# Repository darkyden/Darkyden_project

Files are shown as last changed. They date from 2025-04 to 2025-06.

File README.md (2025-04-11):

# 💻 Diagrammes de cas d'utilisation – Laptop CM3588 Plus

## 🎯 1. Cas d'utilisation – Point de vue de l’utilisateur

```
[État initial : OFF]
    |
    | Appui bouton power (debounce 50 ms)
    v
[BOOTLOADER]
    |
    | Chargement du bootloader (delay: 1-3 sec)
    v
[OS Linux chargé]
    |
    | - Interface graphique active
    | - Réseau détecté?
    |       |-- Oui --> Connexion automatique (delay: 3-5 sec)
    |       |-- Non --> Affichage de l'outil de sélection réseau
    v
[Écran d’accueil / Bureau]
    |
    | Actions possibles :
    | - Lancer terminal
    | - Ouvrir navigateur
    | - Lancer analyse réseau (Nmap, Tshark)
    | - Gérer fichiers
    | - Mise en veille automatique après 10 min inactivité
    |
    | Mise en veille : Appui touche ou pad → Retour bureau (delay: <1 sec)
    |
    | Appui long power (2 sec) → Demande de confirmation d’arrêt
    | → Oui → Arrêt propre du système (3-6 sec)
```

---

## 🧰 2. Cas d'utilisation – Point de vue du technicien

```
[État initial : OFF ou ON]
    |
    | Connexion série UART ou SSH (si actif)
    v
[Console ou TTY active]
    |
    | Tâches possibles :
    | - Flash du bootloader
    | - Modification du fstab, réseau, kernel, uboot
    | - Lecture des logs : dmesg, journalctl
    | - Diagnostic I²C / SPI / USB / PCIe
    | - Interaction GPIO (avec debounce logiciel : 10-100 ms)
    |
    | Commandes système :
    | - reboot → redémarrage (delay: ~5 sec)
    | - halt → arrêt immédiat
    |
    | Monitoring ressources :
    | - top, htop, iotop, powertop
    |
    | Maintenance :
    | - Mise à jour via apt, emerge ou pacman selon distro
    | - Scripts de test de modules (ping module Wi-Fi, test audio I2S)
```

---

## 🔁 Transitions entre états (simplifiées)

```
OFF --> [Appui bouton power] --> BOOTLOADER --> [OS Linux]
OS Linux --> [Inactivité 10 min] --> VEILLE
VEILLE --> [Mouvement souris/clavier] --> OS Linux
OS Linux --> [Appui long 2s + validation] --> SHUTDOWN
```

---

## ⏱ Détails sur les délais

| Action | Délai approximatif |
|---|---|
| Debounce bouton | 50 ms |
| Bootloader | 1 – 3 sec |
| Démarrage complet Linux | 5 – 10 sec |
| Connexion Wi-Fi | 3 – 5 sec |
| Mise en veille automatique | 10 min (paramétrable)  |
| Réveil de veille | < 1 sec |
| Arrêt complet | 3 – 6 sec |
| Temps de réponse CLI (console)  | instantané (<100 ms) |

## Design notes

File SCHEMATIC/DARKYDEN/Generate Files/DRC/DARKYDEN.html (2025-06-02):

Altium

# Design Rule Verification Report

Date: | | 2025-05-15
Time: | | 12:12:37 PM
Elapsed Time: | | 00:00:02
Filename: | | D:\gitdoc\Darkyden_project\SCHEMATIC\DARKYDEN\PCB1.PcbDoc

Warnings: | | 0
Rule Violations: | | 54

## Summary

Warnings | Count
Total | 0

Rule Violations | Count
Clearance Constraint (Gap=0.102mm) (All),(All) | 0
Clearance Constraint (Gap=0.203mm) (inpoly),(All) | 0
Short-Circuit Constraint (Allowed=No) (All),(All) | 0
Un-Routed Net Constraint ( (All) ) | 0
Modified Polygon (Allow modified: No), (Allow shelved: No) | 0
Width Constraint (Min=0.15mm) (Max=5mm) (Preferred=0.2mm) (InNet('+12')) | 0
Width Constraint (Min=0.15mm) (Max=5mm) (Preferred=0.2mm) (InNet('+3V3_NVME')) | 0
Width Constraint (Min=0.15mm) (Max=5mm) (Preferred=0.2mm) (InNet('+3V3')) | 0
Width Constraint (Min=0.15mm) (Max=5mm) (Preferred=0.2mm) (InNet('+5V')) | 0
Width Constraint (Min=0.15mm) (Max=1.27mm) (Preferred=0.152mm) (All) | 0
Width Constraint (Min=0.15mm) (Max=5mm) (Preferred=0.2mm) (InNet('+3V3_WIFI')) | 0
Width Constraint (Min=0.15mm) (Max=5mm) (Preferred=0.2mm) (InNet('+3V3_SD_SO')) | 0
Width Constraint (Min=0.2mm) (Max=0.406mm) (Preferred=0.381mm) (InNet('GND')) | 0
Width Constraint (Min=0.15mm) (Max=5mm) (Preferred=0.2mm) (InNet('+3V3_SD_SO')) | 0
Width Constraint (Min=0.15mm) (Max=5mm) (Preferred=0.2mm) (InNet('+3V3_PI6C')) | 0
Width Constraint (Min=0.15mm) (Max=5mm) (Preferred=0.2mm) (InNet('+1V8')) | 0
Power Plane Connect Rule(Relief Connect )(Expansion=0.508mm) (Conductor Width=0.254mm) (Air Gap=0.254mm) (Entries=4) (All) | 0
Matched Lengths(Tolerance=0.152mm) (InDifferentialPairClass('NVME_DIFF')) | 8
Matched Lengths(Tolerance=50mm) (InDifferentialPairClass('NVME_DIFF')) | 21
Matched Lengths(Tolerance=50mm) (InDifferentialPairClass('WIFI_DIFF')) | 4
Matched Lengths(Tolerance=0.152mm) (InDifferentialPairClass('WIFI_DIFF')) | 4
Matched Lengths(Tolerance=50mm) (InDifferentialPairClass('eDP')) | 0
Matched Lengths(Tolerance=0.152mm) (InDifferentialPairClass('Ethernet')) | 4
Matched Lengths(Tolerance=50mm) (InDifferentialPairClass('Ethernet')) | 0
Matched Lengths(Tolerance=0.152mm) (InDifferentialPairClass('eDP')) | 0
Matched Lengths(Tolerance=50mm) (InDifferentialPairClass('USBC_A') or InDifferentialPairClass('USBC_B')) | 9
Matched Lengths(Tolerance=0.152mm) (InDifferentialPairClass('USBC_A') or InDifferentialPairClass('USBC_B')) | 4
Total | 54

Matched Lengths(Tolerance=0.152mm) (InDifferentialPairClass('NVME_DIFF'))

Matched Net Lengths: Between Net NVME_REFCLK_A_N And Net NVME_REFCLK_A_P Actual Difference against NVME_REFCLK_A_P is: 1.472mm, Tolerance : 0.152mm.

Matched Net Lengths: Between Net PCIE30_PORT0_IN_REFCLK_N And Net PCIE30_PORT0_IN_REFCLK_P Actual Difference against PCIE30_PORT0_IN_REFCLK_P is: 0.223mm, Tolerance : 0.152mm.

Matched Net Lengths: Between Net PCIE30_PORT0_RX1_N And Net PCIE30_PORT0_RX1_P Actual Difference against PCIE30_PORT0_RX1_P is: 0.46mm, Tolerance : 0.152mm.

Matched Net Lengths: Between Net PCIE30_PORT1_IN_REFCLK_N And Net PCIE30_PORT1_IN_REFCLK_P Actual Difference against PCIE30_PORT1_IN_REFCLK_P is: 1.674mm, Tolerance : 0.152mm.

Matched Net Lengths: Between Net PCIE30_PORT1_RX2_N And Net PCIE30_PORT1_RX2_P Actual Difference against PCIE30_PORT1_RX2_P is: 0.206mm, Tolerance : 0.152mm.

Matched Net Lengths: Between Net PCIE30_PORT1_RX3_N And Net PCIE30_PORT1_RX3_P Actual Difference against PCIE30_PORT1_RX3_P is: 3.197mm, Tolerance : 0.152mm.

Matched Net Lengths: Between Net PCIE30_PORT1_TX2_N And Net PCIE30_PORT1_TX2_P Actual Difference against PCIE30_PORT1_TX2_P is: 0.196mm, Tolerance : 0.152mm.

Matched Net Lengths: Between Net WIFI_REFCLK_A_N And Net WIFI_REFCLK_A_P Actual Difference against WIFI_REFCLK_A_P is: 0.48mm, Tolerance : 0.152mm.

Back to top

Matched Lengths(Tolerance=50mm) (InDifferentialPairClass('NVME_DIFF'))

Matched Net Lengths: Differential Pair CLK Actual Length Difference against diff pair PCIE30_PORT1_RX3 is: 96.648mm, Length Tolerance : 50mm.

Matched Net Lengths: Differential Pair CLK1 Actual Length Difference against diff pair PCIE30_PORT1_RX3 is: 98.442mm, Length Tolerance : 50mm.

Matched Net Lengths: Differential Pair CLK2 Actual Length Difference against diff pair PCIE30_PORT1_RX3 is: 98.594mm, Length Tolerance : 50mm.

Matched Net Lengths: Differential Pair CLK3 Actual Length Difference against diff pair PCIE30_PORT1_RX3 is: 96.796mm, Length Tolerance : 50mm.

Matched Net Lengths: Differential Pair PCIE30_PORT0_IN_REFCLK Actual Length Difference against diff pair PCIE30_PORT1_RX3 is: 87.589mm, Length Tolerance : 50mm.

Matched Net Lengths: Differential Pair PCIE30_PORT1_IN_REFCLK Actual Length Difference against diff pair PCIE30_PORT1_RX3 is: 79.867mm, Length Tolerance : 50mm.

Matched Net Lengths: Differential Pair WIFI_REFCLK_A Actual Length Difference against diff pair PCIE30_PORT1_RX3 is: 67.314mm, Length Tolerance : 50mm.

Matched Net Lengths: Between Net CLK_N And Net PCIE30_PORT1_RX3_P Length:7.098mm is not within 50mm tolerance of Length:105.345mm (48.246mm short)

Matched Net Lengths: Between Net CLK_P And Net PCIE30_PORT1_RX3_P Length:7.098mm is not within 50mm tolerance of Length:105.345mm (48.246mm short)

Matched Net Lengths: Between Net CLK1_N And Net PCIE30_PORT1_RX3_P Length:5.305mm is not within 50mm tolerance of Length:105.345mm (50.04mm short)

Matched Net Lengths: Between Net CLK1_P And Net PCIE30_PORT1_RX3_P Length:5.305mm is not within 50mm tolerance of Length:105.345mm (50.04mm short)

Matched Net Lengths: Between Net CLK2_N And Net PCIE30_PORT1_RX3_P Length:5.152mm is not within 50mm tolerance of Length:105.345mm (50.192mm short)

Matched Net Lengths: Between Net CLK2_P And Net PCIE30_PORT1_RX3_P Length:5.152mm is not within 50mm tolerance of Length:105.345mm (50.192mm short)

Matched Net Lengths: Between Net CLK3_N And Net PCIE30_PORT1_RX3_P Length:6.95mm is not within 50mm tolerance of Length:105.345mm (48.394mm short)

Matched Net Lengths: Between Net CLK3_P And Net PCIE30_PORT1_RX3_P Length:6.95mm is not within 50mm tolerance of Length:105.345mm (48.394mm short)

Matched Net Lengths: Between Net PCIE30_PORT0_IN_REFCLK_N And Net PCIE30_PORT1_RX3_P Length:16.045mm is not within 50mm tolerance of Length:105.345mm (39.299mm short)

Matched Net Lengths: Between Net PCIE30_PORT0_IN_REFCLK_P And Net PCIE30_PORT1_RX3_P Length:16.268mm is not within 50mm tolerance of Length:105.345mm (39.076mm short)

Matched Net Lengths: Between Net PCIE30_PORT1_IN_REFCLK_N And Net PCIE30_PORT1_RX3_P Length:23.043mm is not within 50mm tolerance of Length:105.345mm (32.302mm short)

Matched Net Lengths: Between Net PCIE30_PORT1_IN_REFCLK_P And Net PCIE30_PORT1_RX3_P Length:24.717mm is not within 50mm tolerance of Length:105.345mm (30.628mm short)

Matched Net Lengths: Between Net PCIE30_PORT1_RX3_P And Net WIFI_REFCLK_A_N Length:36.192mm is not within 50mm tolerance of Length:105.345mm (19.152mm short)

Matched Net Lengths: Between Net PCIE30_PORT1_RX3_P And Net WIFI_REFCLK_A_P Length:36.672mm is not within 50mm tolerance of Length:105.345mm (18.672mm short)

Back to top

Matched Lengths(Tolerance=50mm) (InDifferentialPairClass('WIFI_DIFF'))

Matched Net Lengths: Differential Pair WIFI_REFCLK_A Actual Length Difference against diff pair USB20_HOST1_D is: 77.598mm, Length Tolerance : 50mm.

Matched Net Lengths: Between Net PCIE20_1_TX_N And Net USB20_HOST1_D_P Length:63.948mm is not within 50mm tolerance of Length:114.272mm (0.324mm short)

Matched Net Lengths: Between Net USB20_HOST1_D_P And Net WIFI_REFCLK_A_N Length:36.192mm is not within 50mm tolerance of Length:114.272mm (28.08mm short)

Matched Net Lengths: Between Net USB20_HOST1_D_P And Net WIFI_REFCLK_A_P Length:36.672mm is not within 50mm tolerance of Length:114.272mm (27.6mm short)

Back to top

Matched Lengths(Tolerance=0.152mm) (InDifferentialPairClass('WIFI_DIFF'))

Matched Net Lengths: Between Net PCIE20_1_RX_N And Net PCIE20_1_RX_P Actual Difference against PCIE20_1_RX_P is: 1.02mm, Tolerance : 0.152mm.

Matched Net Lengths: Between Net PCIE20_1_TX_N And Net PCIE20_1_TX_P Actual Difference against PCIE20_1_TX_P is: 0.454mm, Tolerance : 0.152mm.

Matched Net Lengths: Between Net USB20_HOST1_D_N And Net USB20_HOST1_D_P Actual Difference against USB20_HOST1_D_P is: 0.484mm, Tolerance : 0.152mm.

Matched Net Lengths: Between Net WIFI_REFCLK_A_N And Net WIFI_REFCLK_A_P Actual Difference against WIFI_REFCLK_A_P is: 0.48mm, Tolerance : 0.152mm.

Back to top

Matched Lengths(Tolerance=0.152mm) (InDifferentialPairClass('Ethernet'))

Matched Net Lengths: Between Net P25G_MDI0_N And Net P25G_MDI0_P Actual Difference against P25G_MDI0_P is: 1.032mm, Tolerance : 0.152mm.

Matched Net Lengths: Between Net P25G_MDI1_N And Net P25G_MDI1_P Actual Difference against P25G_MDI1_P is: 2.328mm, Tolerance : 0.152mm.

Matched Net Lengths: Between Net P25G_MDI2_N And Net P25G_MDI2_P Actual Difference against P25G_MDI2_P is: 1.228mm, Tolerance : 0.152mm.

Matched Net Lengths: Between Net P25G_MDI3_N And Net P25G_MDI3_P Actual Difference against P25G_MDI3_P is: 1.979mm, Tolerance : 0.152mm.

Back to top

Matched Lengths(Tolerance=50mm) (InDifferentialPairClass('USBC_A') or InDifferentialPairClass('USBC_B'))

Matched Net Lengths: Differential Pair TYPEC0_D Actual Length Difference against diff pair TYPEC1_OTG_D is: 91.41mm, Length Tolerance : 50mm.

Matched Net Lengths: Differential Pair TYPEC0_OTG Actual Length Difference against diff pair TYPEC1_OTG_D is: 54.508mm, Length Tolerance : 50mm.

Matched Net Lengths: Differential Pair TYPEC1_D Actual Length Difference against diff pair TYPEC1_OTG_D is: 90.068mm, Length Tolerance : 50mm.

Matched Net Lengths: Between Net TYPEC0_D_N And Net TYPEC1_OTG_D_P Length:21.341mm is not within 50mm tolerance of Length:113.87mm (42.529mm short)

Matched Net Lengths: Between Net TYPEC0_D_P And Net TYPEC1_OTG_D_P Length:21.418mm is not within 50mm tolerance of Length:113.87mm (42.453mm short)

Matched Net Lengths: Between Net TYPEC0_OTG_N And Net TYPEC1_OTG_D_P Length:58.587mm is not within 50mm tolerance of Length:113.87mm (5.283mm short)

Matched Net Lengths: Between Net TYPEC0_OTG_P And Net TYPEC1_OTG_D_P Length:57.976mm is not within 50mm tolerance of Length:113.87mm (5.894mm short)

Matched Net Lengths: Between Net TYPEC1_D_N And Net TYPEC1_OTG_D_P Length:22.741mm is not within 50mm tolerance of Length:113.87mm (41.13mm short)

Matched Net Lengths: Between Net TYPEC1_D_P And Net TYPEC1_OTG_D_P Length:22.703mm is not within 50mm tolerance of Length:113.87mm (41.168mm short)

Back to top

Matched Lengths(Tolerance=0.152mm) (InDifferentialPairClass('USBC_A') or InDifferentialPairClass('USBC_B'))

Matched Net Lengths: Between Net TYPEC0_OTG_N And Net TYPEC0_OTG_P Actual Difference against TYPEC0_OTG_P is: 0.611mm, Tolerance : 0.152mm.

Matched Net Lengths: Between Net TYPEC0_SSTX1_N And Net TYPEC0_SSTX1_P Actual Difference against TYPEC0_SSTX1_P is: 0.184mm, Tolerance : 0.152mm.

Matched Net Lengths: Between Net TYPEC1_OTG_D_N And Net TYPEC1_OTG_D_P Actual Difference against TYPEC1_OTG_D_P is: 2.162mm, Tolerance : 0.152mm.

Matched Net Lengths: Between Net TYPEC1_SSRX2_N And Net TYPEC1_SSRX2_P Actual Difference against TYPEC1_SSRX2_P is: 0.154mm, Tolerance : 0.152mm.

Back to top

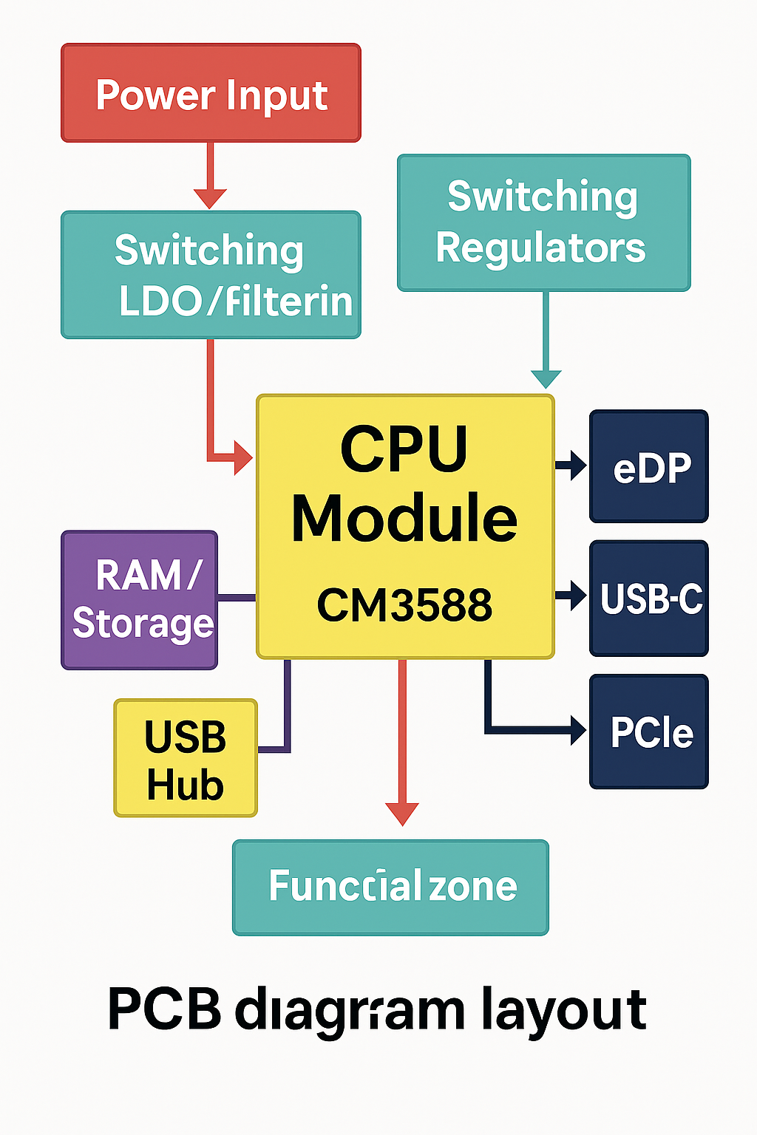
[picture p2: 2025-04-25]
DATASHEET/layout.png

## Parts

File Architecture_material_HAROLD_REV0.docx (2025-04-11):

# Projet de fin de DEC – Architecture matérielle

Projet : Laptop basé sur le CM3588 Plus
OS principal : Linux

# Architecture Matérielle

## 1. Composantes matérielles principales

- SoC principal : CM3588 Plus (CPU ARM Cortex-A76/A55, GPU Mali-G610)
- Mémoire vive (RAM) : 64bits 16Go LPDDR5 @2400MHz
- Stockage principal : SSD NVMe via M.2
- Wi-Fi / Bluetooth : Module Intel AX210 (Wi-Fi 6E, Bluetooth 5.3)
- Réseautique : Port Ethernet RJ45 Gigabit
- USB : 2 ports USB-C (dont un pour la charge), 2 ports USB 3.0 Type-A
- Affichage : Écran LCD entre 13.3 à 16 pouces via eDP
- Alimentation : Batterie Li-ion 4S (~14.8V nominal, 16.8V max), recharge via USB-C PD

## 2. Alimentation

- Type : Batterie Li-ion 4S
- Tension : 14.8V nominale, 16.8V pleine charge
- Recharge : USB-C Power Delivery via module BQ25792
- Régulation : Buck converter TPS564201 pour 3.3V, avec filtrage pour SSD, Wi-Fi

## 3. Emplacement des composantes

Disposition prévue sur le PCB : CM3588 centré, SSD à l’arrière, ports USB/C de chaque côté, batterie dessous.

## 4. Dimensions

- PCB : ~220mm x 140mm (1ere estimation)
- Composantes critiques : NVMe, AX210 (hauteur)
- Fixation : stand-offs métalliques M2.5, boîtier imprimé 3D

## 5. Analyse des pièces

- CM3588 Plus : ~80-120$
- AX210 : ~30$
- NVMe : courant
- Régulateurs TPS564201 : disponibles
- Contrôleur PD : BQ25792 (~10$)

## 6. Calculs de courant et puissance

- Total : ~15-20W
- Batterie 4S 4000mAh ≈ 60Wh ⇒ 3-4h autonomie

## 7. Analyse PCB vs impédance

PCB 6 couches, impédance contrôlée sur lignes USB 3.0, PCIe, eDP.

## 8. Schéma bloc simplifié

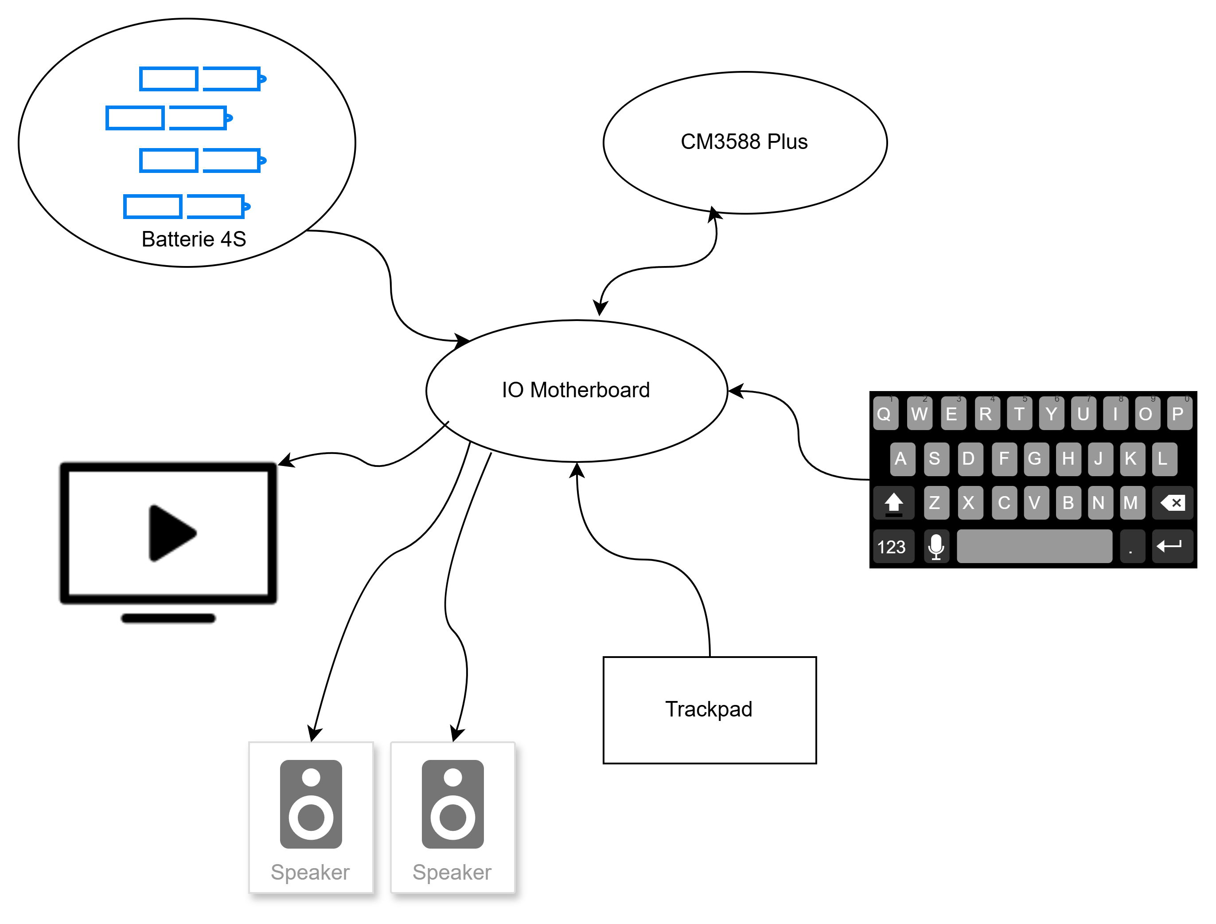
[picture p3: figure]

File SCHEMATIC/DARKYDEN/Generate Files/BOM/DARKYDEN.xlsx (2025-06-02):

LibRef | Comment | Manufacturer | Quantity | Description | Designator | Manufacturer Part Number
C0805C223J3GACTU | 22nf/25V | KEMET | 1 | 22nF, 25 V, 0805 [2012 Metric], 5%, C0G / NP0 | 66 | C0805C223J3GACTU
BGX50AE6327HTSA1 | BGX50AE6327HTSA1 | Infineon | 5 | BGX50A Series 50 V 140 mA Surface Mount Silicon Switching Diode - SOT-143 | BR1, BR2, BR3, BR4, BR5 | BGX50AE6327HTSA1
Header 1.25MM | 0530480210 |  | 4 | Connector | BT1, BT2, BT3, BT4 | 0530480210
C0805C104K9RACTU | 0.1uF/6.3V | KEMET | 19 | 0.1uF 6.3V X7R 10% Pad SMD 0805 125C T/R | C1, C156, C158, C159, C160, C162, C163, C164, C165, C166, C168, C171, C172, C175, C176, C179, C180, C183, C185 | C0805C104K5RACTU
C0805C106K9RACTU | 10uF/6.3V | KEMET | 9 | 10uF/6.3V SMD Comm X7R 0805 (2012Metric) Ceramic Capacitor 0.079Lx0.049W 2.00mmx1.25mm X7R ±10% 10muF | C2, C3, C6, C7, C12, C13, C14, C15, C35 | C0805C106K3PACTU
C0805C221M5RACTU | 220pF/50V | KEMET | 4 | Cap Ceramic 220pF 50V X7R 20% Pad SMD 0805 125C T/R | C4, C5, C19, C20 | C0805C221M5RACTU
C0805C105K9RACTU | 1uF/6.3V | KEMET | 8 | 1 uF, 6.3 V, ± 10%, X7R, 0805 [2012 Metric] Multilayer Ceramic Capacitor, | C8, C9, C10, C16, C17, C18, C21, C22 | C0805C105K3RACTU
EEE-FPJ101UAR | 100uF / 6.3V | Panasonic | 6 | 100uF 6.3V 20% Cap Aluminum Lytic SMD 0.36 Ohm 240mA 2000h 105C Automotive T/R | C11, C169, C173, C177, C181, C186 | EEE-FPJ101UAR
C0805C104K4RACAUTO | 0.1uF/16V | KEMET | 8 | 0.1uF/16V ±10% X7R 0805 (2012METRIC) Ceramic Capacitor SMD Auto X7R | C23, C24, C29, C31, C36, C45, C137, C138 | C0805C104K5RACTU
C0805C105K8RACTU | 1uF/10V | KEMET | 8 | Multilayer Ceramic Capacitors MLCC - SMD/SMT 10V 1uF X7R 0805 10% | C26, C28, C30, C32, C49, C58, C70, C79 | C0805C105K3RACTU
C0805C220J5RACTU | 22pF/50V | KEMET | 6 | Cap Ceramic 22pF 50V X7R 5% Pad SMD 0805 125°C T/R | C27, C51, C60, C72, C81, C151 | C0805C220J5RACTU
C0805C150K5RACAUTO | 15pF/50V | KEMET | 2 | Multilayer Ceramic Capacitors MLCC - SMD/SMT 50V 15pF X7R 0805 10% AEC-Q200 | C33, C34 | C0805C150K5RACAUTO
C0805C102K5RACTU | 1nF/50V | KEMET | 10 | Multilayer Ceramic Capacitor 1000 Pf 50 V ½ 10% X7R 0805 [2012 Metric] | C41, C42, C43, C44, C115, C155, C170, C174, C178, C182 | C0805C102K5RACTU
C0805C105K4RACTU | 1uF/16V | KEMET | 2 | 1uF/16 V, X7R, Surface Mount, 0805 | C46, C154 | C0805C105K3RACTU
C0805C106K3PACTU | 10uF/25V | KEMET | 43 | 10uF / 25 VDC, +85degC, X5R Dielec, +/-10% | KEMET C0805C106K3PACTU 0805 | C47, C48, C52, C53, C54, C55, C56, C57, C61, C62, C63, C64, C65, C68, C69, C73, C74, C75, C76, C77, C78, C82, C83, C84, C85, C87, C88, C89, C95, C96, C98, C99, C100, C101, C107, C108, C109, C110, C111, C113, C114, C152, C153 | C0805C106K3PACTU
C0805C104K3RACTU | 0.1uF/25V | KEMET | 11 | 0.1uF 25V X7R 10% SMD 0805 125C Plastic T/R | C50, C59, C71, C80, C94, C122, C123, C124, C126, C127, C142 | C0805C104K5RACTU
C0805C105K3RACTU | 1uF/25V | KEMET | 9 | 1 µF, 25 V (DC), ±10 %, SMD 0805, X7R, C0805C105K3RAC7800 | C67, C116, C117, C120, C121, C125, C128, C129, C131 | C0805C105K3RACTU
C0805C103K3RACTU | 10nF/25V | KEMET | 2 | 0.01uF 25V X7R 10% SMD 0805 125C Paper T/R | C86, C149 | C0805C103K3RACTU
C0805C331K3GACTU | 330pF/25V | KEMET | 2 | 330pF 25VC0G 0805 10% | C90, C91 | C0805C331K3GACTU
CL21A226MAYNNNE | 22pF/25V | Samsung | 2 | 22uF/25V 20% X5R 0805 | C92, C93 | CL21A226MAYNNNE
C0805C104K5RACTU | 0.1uF/50V | KEMET | 4 | 0.1uF/50V X7R 10% 0805 Multilayer Ceramic Capacitors Mlcc Smd/Smt Rohs | C97, C102, C106, C112 | C0805C104K5RACTU
C0805C475K4RACTU | 4.7uF/16V | KEMET | 2 | 4.7 uF, 16 V, ± 10%, X7R, 0805 [2012 Metric] | C103, C141 | C0805C475K4RACTU
C0805C473K3GACTU | 47nF/25V | KEMET | 2 | 47nF/25V C0G 10% Pad SMD 0805 125C Extreme Low ESR T/R | C104, C105 | C0805C473K3GACTU
GRM32ER61E226KE15L | 22uF/25V | Murata | 1 | 1210 22 uF 25 V ±10% Tolerance X5R SMT Multilayer Ceramic Capacitor | C132 | GRM32ER61E226KE15L
20SVPF56MX | 56uF/20V | Panasonic | 1 | 56uF 20VDC 20%( Cap Aluminum Polymer SMD 0.03 Ohm 2800mA 5000h 105C T/R 20SVPF56MX | C133 | 20SVPF56MX
35SVPF120M | 120uF/35V | Panasonic | 1 | 120uF 35VDC 20% Cap Aluminum Polymer SMD 0.018 Ohm 4400mA 5000h 105C T/R | C134 | 35SVPF120M
C3225X7R1H106M250AC | 10uF/50V | TDK | 1 | 10 uF 50 V 1210 ±20 % Tolerance X7R SMT Multilayer Ceramic Capacitor | C135 | C3225X7R1H106M250AC
C1608X5R1H105K080AB | 1uF/50V | TDK | 1 | 1uF / 50 V, X5R, Surface Mount, 0603 | C136 | C1608X5R1H105K080AB
C0805C472K4RACTU | 4.7nF/16V | KEMET | 1 | 4.7nF, 16VDC, 10-% Tol, 10+% Tol, X7R-TC Code, -15, 15%-TC RoHS Compliant: Yes | C139 | C0805C472K4RACTU
C0805C150K4GACTU | 15pF/16V | KEMET | 1 | 15 pF, 16 V, ± 10%, C0G (NP0), 0805 [2012 Metric] | C140 | C0805C150K5RACAUTO
CGA4J3X5R1H475K125AB | 4.7uF/50V | TDK | 2 | 4.7uF/50V X5R 卤10% 0805 Multilayer Ceramic Capacitors MLCC - SMD/SMT ROHS | C143, C144 | CGA4J3X5R1H475K125AB
C0805C103K5RACTU | 10nF/50V | KEMET | 1 | 10nF/50V X7R 0805 10% | C145 | C0805C103K5RACTU
T520B107M006ATE015 | 100uF/6.3V | KEMET | 1 | 100uF / 6.3VDC B CASE 20% Cap Tant Polymer SMD 3528-21 0.015 Ohm 105C T/R | C146 | T520B107M006ATE015
GRM32ER61A476KE20L | 47uF/10V | Murata | 2 | Multilayer Ceramic Capacitor, 47 uF, 10 V, ï¿½ 10%, X5R, 1210 [3225 Metric] | C147, C148 | GRM32ER61A476KE20L
C0805C222K3GECTU | 2.2nF/25V | KEMET | 1 | 2.2nF ±10% 25V Ceramic Capacitor C0G, NP0 0805 (2012 Metric) | C150 | C0805C222K3GECTU
C0805C475K9RACTU | 4.7uF / 6.3V | KEMET | 1 | 4.7uF 6.3V X7R 10% Pad SMD 0805 125C T/R | C157 | C0805C475K9RACTU
C0805C180K5RACTU | 18pF/50V | KEMET | 2 | 18PF, 50V, Mlcc, 0805; | C161, C167 | C0805C180K5RACTU
DF40HC(3.0)-100DS-0.4V(51) | DF40HC | Hirose | 4 | Stacking Board Connector, DF40 Series, Receptacle, 0.4 mm, 100, Surface Mount, G | CON1, CON2, CON3, CON4 | DF40HC(3.0)-100DS-0.4V(51
RB521S30T1G | 30V/200mA | ON Semiconductor | 1 | SCHOTTKY BARRIER DIODE Rectifier Diode, Schottky, 1 Phase, 1 Element, 0.2A, 30V V(RRM), Silicon | D3 | RB521S30T1G
BAS316_RRG | BAS316_RRG | Taiwan Semiconductor | 1 | Rectifier Diode Small Signal Switching 0.25A 4ns 2-Pin SOD-323 T/R | D4 | BAS316 RRG
SMBJ26A-13-F | SMBJ26A-13-F |  | 1 | TVS DIODE 26VWM 42.1VC SMB | D5 | SMBJ26A-13-F
MMSZ5248B-7-F | MMSZ5248B-7-F |  | 1 | Zener Diode 18 V 500 mW ±5% Surface Mount SOD-123 | D6 | MMSZ5248B-7-F
CDBC540-G | CDBC540-G | Comchip | 1 | Schottky Diode 40V 5A 2-Pin DO-214AB (SMC) CDBC540-G SMT | D7 | CDBC540-G
20455-040E-76 | 20455-040E-76 | I-PEX | 1 | Conn Wire to Board RCP 40 POS 0.5mm Solder RA Side Entry SMDCABLINE® T/R | eDP1 | 20455-040E-76
L829-1J1T-JM | L829-1J1T-JM | Bel | 1 | Modular Connectors / Ethernet Connectors 1x1 2.5GBT MagJack | ETH1 | L829-1J1T-JM
BLM18EG221SN1D | 220R / 100MHz | Murata | 11 | Ferrite Beads Multi-Layer 220Ohm 25% 100MHz 2A 50mOhm DCR 0603 Paper T/R | FB1, FB2, FB3, FB4, FB5, FB6, FB7, FB8, FB9, FB10, FB11 | BLM18EG221SN1D
AT25SF081B-SHB-T | AT25SF081B-SHB-T | Renesas | 1 | FLASH - NOR Memory IC 8Mb (1M x 8) SPI - Quad I/O 108 MHz 8-SOIC | IC4 | AT25SF081B-SHB-T
TPS564201DDCR | TPS564201DDCR | Texas Instruments | 4 | IC REG BUCK ADJ 4A SOT23 "Buck Switching Regulator IC Positive Adjustable 0.76V 1 Output 4A SOT-23-6 Thin, TSOT-23-6" | IC5, IC6, IC8, IC9 | TPS564201DDCR
RT9193-18GB | RT9193-18GB |  | 1 | Linear Voltage Regulator IC Positive Fixed 1.8V Output 300mA SOT-23-5 | IC7 | RT9193-18GB
BQ7791501PWR | BQ7791501PWR | Texas Instruments | 1 | /Polymer 3~5 TSSOP-24 Battery Management ICs ROHS | IC12 | BQ7791501PWR
TPS552882RPMR | TPS552882RPMR | Texas Instruments | 1 | 36-V, 16-A buck-boost converter 26-VQFN-HR -40 to 125 | IC14 | TPS552882RPMR
TPS54531DDA | TPS54531DDA |  | 1 | Buck Switching Regulator IC Positive Adjustable 0.8V 1 Output 5A 8-PowerSOIC (0.154", 3.90mm Width) | IC15 | TPS54531DDA
TLV75533PDBVR | TLV75533PDBVR | Texas Instruments | 1 | 500mA high-PSRR low-IQ low-dropout voltage regulator with enable 5-SOT-23 -40 to 125 | IC16 | TLV75533PDBVR
USB2514B-AEZG | USB2514B-AEZG |  | 1 | USB Hub Controller USB 2.0 USB Interface 36-QFN (6x6) | IC17 | USB2514B-AEZG
MIC2505-1YM | MIC2505-1YM |  | 1 | Power Switch/Driver 1:1 N-Channel 2A 8-SOIC | IC18 | MIC2505-1YM
MIC2026-1YM | MIC2026-1YM |  | 2 | Power Switch/Driver 1:2 N-Channel 1.25A 8-SOIC | IC19, IC20 | MIC2026-1YM
USBC | USBC |  | 3 | USB-C (USB TYPE-C) USB 3.2 Gen 2 (USB 3.1 Gen 2, Superspeed + (USB 3.1)) Receptacle Connector 24 Position Surface Mount, Right Angle; Through Hole | J2, J3, J8 | 2012670005
2328702-8 | 2328702-8 |  | 1 | Connector | J4 | 2328702-8
MSD-4-A | MicroSD |  | 1 | Micro SD Card Connector, 9 Positions, Connector and Ejector, Push In, Auto Eject Out, Surface Mount, 1.8 mm Height Above Board, Gold Flash | J7 | MSD-4-A
61300311121 | 61300311121 | Wurth Elektronik | 1 | WR-PHD Pin Header, THT, Vertical, pitch 2.54mm, 1 Row, 3P | J12 | 61300311121
61300211121 | PowerOn_btn | Wurth Electronics | 1 | THT Vertical Pin Header WR-PHD, Pitch 2.54 mm, Single Row, 2 pins | J17 | 61300211121
Header_2x1 | PW_SYS_BAK | Sullins Connector Solutions | 1 | Header, 100mil, 2x1, Tin, TH | JP1
Header_2x1 | POWER_BAK | Sullins Connector Solutions | 1 | Header, 100mil, 2x1, Tin, TH | JP2
Header_2x1 | TS | Sullins Connector Solutions | 1 | Header, 100mil, 2x1, Tin, TH | JP3
ACM2012-900-2P-T002 | 400mA / 90 Ohm | TDK | 7 | Ferrite Beads Wirewound Common Mode Filter 90Ohm 100MHz 400mA 0805 T/R | L1, L2, L19, L20, L21, L22, L23 | ACM2012-900-2P-T002
ACM2012-900-2P-T002 | ACM2012-900-2P-T002 | TDK | 7 | Ferrite Beads Wirewound Common Mode Filter 90Ohm 100MHz 400mA 0805 T/R | L3, L4, L5, L6, L28, L29, L30 | ACM2012-900-2P-T002
MWSA0605S-3R3MT | MWSA0605S-3R3MT |  | 1 | 3.3 µH Shielded Drum Core, Wirewound Inductor 8.5 A 22mOhm Max Nonstandard | L11 | MWSA0605S-3R3MT
WPN4020H2R2MT | WPN4020H2R2MT | Sunlord | 3 | 2.2 µH Shielded Drum Core, Wirewound Inductor 4.3 A 48mOhm Max Nonstandard | L12, L13, L14 | WPN4020H2R2MT
FBMJ2125HM210NT | FBMJ2125HM210NT | Taiyo Yuden | 5 | Ferrite Beads Power Chip 21Ohm 30% 100MHz 6A 0.004Ohm DCR 0805 Automotive T/R | L15, L24, L25, L26, L27 | FBMJ2125HM210NT
IHLP2020BZER1R0M11 | IHLP2020BZER1R0M11 | Vishay-Dale | 1 | Inductor, Shielded Drum Core, Powdered Iron, 1 uH, 7 A, 0.0181 ohm, SMD | L16 | IHLP2020BZER1R0M11
PA4343.822ANLT | 8.2pH/13.8mOhms | Pulse | 1 | Inductor Power Shielded/Molded Wirewound 8.2uH 20% 100KHz 15A 0.0138Ohm DCR Automotive T/R | L17 | PA4343.822ANLT
74437368047 | 74437368047 | Wurth Electronics | 1 | WE-LHMI SMT POWER INDUCTOR General Purpose Inductor, 4.7uH, 20%, 1 Element, Powdered Iron-Core, SMD, 4339 | L18 | 74437368047
GREEN | Green, 3.2V, 140° | Wurth Elektronik | 2 | WL-SMCD Mono-color Chip LED Diffused, SMT, size 0603, Green, 3.2V, 140° | LED1, LED8 | 150060GS55040
BLUE | Blue, 3.2V, 140° | Wurth Elektronik | 1 | WL-SMCD Mono-color Chip LED Diffused, SMT, size 0603, Blue, 3.2V, 140° | LED2 | 150060BS55040
LED_Gr_SMD | LTST-C190GKT | Lite-On | 5 | LED, Green, SMD | LED3, LED4, LED5, LED6, LED7 | LTST-C190GKT
SW_SMT | SW_SMT | Same Sky | 4 | Switch Tactile OFF (ON) SPST Round Button Gull Wing 0.05A 12VDC 100000Cycles 1N SMD T/R | Mask, Power, Recovery, Reset | TS06-667-25-BK-100-G-SMT-TR
Bus_M.2_Socket_M | Bus_M.2_Socket_M |  | 1 |  | NVME | MDT420M03001
CSD18514Q5A | CSD18514Q5A |  | 4 | MOSFET N-Channel 40 V 89A (Tc) 74W (Tc) Surface Mount 8-VSONP (5x6) | Q6, Q7, Q8, Q9 | CSD18514Q5A
ERJ-3GEYJ104V | 100k | Panasonic | 15 | 100K Ohm 5% Res Thick Film 0603 1/10W +/-200ppm/ßC Molded SMD Punched Carrier T/R | R1, R10, R23, R90, R114, R128, R147, R148, R160, R163, R166, R167, R169, R170, R171 | ERJ-3GEYJ104V
ERJ-3GEYJ682V | 6.8K | Panasonic | 4 | 6.8 kOhm, ± 5%, 100 mW, 0603 [1608 Metric], Thick Film, General Purpose | R2, R3, R8, R9 | ERJ-3GEYJ682V
ERJ-3GEYJ222V | 2.2K | Panasonic | 7 | 2.2 kOhm, ï¿½ 5%, 100 mW, 0603 [1608 Metric], Thick Film, General Purpose | R4, R5, R11, R12, R41, R109, R110 | ERJ-3GEYJ222V
ERJ-3GEY0R00V | 0R | Panasonic | 20 | Zero Ohm Resistor, Jumper, 0603 [1608 Metric], Thick Film, 100 mW, 1 A, Surface Mount | R6, R7, R19, R20, R21, R42, R43, R74, R79, R80, R84, R85, R89, R93, R94, R98, R99, R162, R173, R174 | ERJ-3GEY0R00V
ERJ-3GEYJ103V | 10K | Panasonic | 24 | 10K Ohm 5% Res Thick Film 0603 0.1W(1/10W) ±200ppm/C Pad SMD Automotive T/R | R13, R22, R26, R27, R75, R76, R77, R81, R83, R86, R88, R95, R97, R100, R102, R104, R105, R106, R108, R117, R120, R127, R129, R164 | ERJ-3GEYJ103V
ERJ-3EKF5600V | 560R | Panasonic | 4 | 560 Ohm, ï¿½ 1%, 100 mW, 0603 [1608 Metric], Thick Film, Precision | R14, R15, R16, R17 | ERJ-3EKF5600V
ERJ-3GEYJ473V | 47K | Panasonic | 1 | 47K Ohm 5% 1/10W 0603 200ppm/C Molded SMD Punched Carrier T/R | R18 | ERJ-3GEYJ473V
ERA-3AEB472V | 4.7K | Panasonic | 3 | 4.7K Ohm 0.1% 0.1W 0603 ±25ppm/°C Molded SMD Punched Carrier T/R | R24, R103, R107 | ERA-3AEB472V
ERJ-3EKF1000V | 100R | Panasonic | 8 | 100 Ohm 1% 1/10W 0603 ±100ppm/°C Molded SMD Punched Carrier T/R | R25, R70, R71, R72, R73, R111, R135, R136 | ERJ-3EKF1000V
ERJ-3EKF33R0V | 33R | Panasonic | 21 | 33 Ohm 1% 0.1W 0603 ±100ppm/°C Molded SMD Punched Carrier T/R | R28, R29, R32, R33, R34, R35, R44, R45, R46, R47, R48, R49, R50, R78, R118, R119, R126, R131, R133, R137, R139 | ERJ-3EKF33R0V
ERJ-3EKF49R9V | 49.9R | Panasonic | 8 | 100Mw Thick Film Resistors 100Ppm/ 1% 49.9 0603 Chip Resistor Surface Mount Rohs | R30, R31, R37, R38, R39, R40, R121, R159 | ERJ-3EKF49R9V
ERJ-3GEYJ471V | 470R | Panasonic | 1 | 470 Ohm 5% 1/10W 0603 +/-200ppm/ßC Molded SMD Punched Carrier T/R | R36 | ERJ-3GEYJ471V
ERJ-3GEYJ334V | 330K | Panasonic | 1 | 330 kOhm, ± 5%, 100 mW, 0603 [1608 Metric], Thick Film, General Purpose | R51 | ERJ-3GEYJ334V
ERJ-3LWJR010V | 10mOhms | Panasonic | 1 | 10 Milliohm, ± 5%, 250 mW, 0603 [1608 Metric], Thick Film, High Power | R52 | ERJ-3LWJR010V
ERJ-3EKF5602V | 56K | Panasonic | 1 | 56K Ohm 1% 1/10W +/-100ppm/ßC Molded SMD Punched Carrier T/R | R82 | ERJ-3EKF5602V
ERJ-3GEYJ333V | 33K | Panasonic | 3 | 33K Ohm 0603 5% 0.1W(1/10W) +/-200ppm/ßC SMD Automotive T/R | R87, R96, R101 | ERJ-3GEYJ333V
ERJ-3GEYJ154V | 150K | Panasonic | 1 | 150 kOhm, ± 5%, 100 mW, 0603 [1608 Metric], Thick Film, General Purpose | R91 | ERJ-3GEYJ154V
ERJ-3EKF2702V | 27K | Panasonic | 1 | 27K Ohm 1% 1/10W 0603 ±100ppm/°C Molded SMD Punched Carrier T/R | R92 | ERJ-3EKF2702V
ERJ-3EKF1742V | 17.4K | Panasonic | 1 | 17.4K Ohm 1% 1/10W +/-100ppm/ßC Molded Res Thick Film 0603 SMD Punched Carrier T/R | R112 | ERJ-3EKF1742V
ERJ-3EKF1373V | 137K | Panasonic | 1 | 137K Ohm 1% 1/10W Res Thick Film 0603 ±100ppm/°C SMD Punched Carrier T/R | R113 | ERJ-3EKF1373V
ERJ-3GEYJ303V | 30K | Panasonic | 1 | 30K Ohm 5% 0.1W(1/10W) +/-200ppm/ßC Res Thick Film 0603 SMD Automotive T/R | R115 | ERJ-3GEYJ303V
ERJ-3EKF5231V | 5.23K | Panasonic | 1 | 5.23K Ohm 1% 1/10W Res Thick Film 0603+/-100ppm/ßC Molded SMD Punched Carrier T/R | R116 | ERJ-3EKF5231V
ERA-3ARW512V | 5.1K | Panasonic | 2 | 5.1K Ohm 0.05% 0.1W ±10ppm/°C Molded Res Thin Film 0603 SMD Punched Carrier T/R | R122, R124 | ERA-3ARW512V
ERJ-3EKF1001V | 1K | Panasonic | 7 | 1K Ohm 1% 1/10W Res Thick Film 0603 ±100ppm/°C Molded SMD Punched Carrier T/R | R123, R130, R132, R134, R143, R161, R165 | ERJ-3EKF1001V
ERJ-3GEYJ105V | 1M | Panasonic | 2 | 1M Ohm Res Thick Film 0603 5% 0.1W(1/10W) +/-200ppm/ßC SMD Automotive T/R | R125, R172 | ERJ-3GEYJ105V
Resistor 2010 | CMP-R015-1.0 |  | 1 | Package 2010 | R138 | CRCW20100000Z0EFHP
ERJ-U03J106V | 10M | Panasonic | 1 | 10Mohm 5% SMD 0603 Anti-Sulfur AEC-Q200 | R140 | ERJ-U03J106V
ERJ-3GEYJ305V | 3M | Panasonic | 1 | 3M Ohm 5% 1/10W Res Thick Film 0603 -400ppm/ || | R141 | ERJ-3GEYJ305V
ERJ-3EKF4703V | 470K | Panasonic | 1 | 470K Ohm 1% 0.1W Res Thick Film 0603 ±100ppm/°C Molded SMD Punched Carrier T/R | R142 | ERJ-3EKF4703V
ERJ-3EKF5493V | 549K | Panasonic | 1 | 549 kOhm, ± 1%, 100 mW, 0603 [1608 Metric], Thick Film, Precision | R144 | ERJ-3EKF5493V
ERJ-3GEYJ1R0V | 1R | Panasonic | 2 | 1 Ohm 5% 1/10W Res Thick Film 0603 -100ppm/ || | R145, R146 | ERJ-3GEYJ1R0V
RT0603BRD0710K4L | 10.4K | Yageo | 1 | 10.4kOhm 0.1% High Precision-High Stability Chip Resistor Thin Film 0603 Paper T/R | R149 | RT0603BRD0710K4L
CRCW040250K0FKED | 50K |  | 1 | 50 kΩ Tolerance: 1.0% Power: 63 mW Package:0402 | R150 | CRCW040250K0FKED
CRCW040231K6FKED | 31.6K |  | 1 | 31.6 kΩ Tolerance: 1.0% Power: 63 mW | R151 | CRCW040231K6FKED
CRCW040254K9FKED | 54.9K |  | 1 | 54.9 kΩ Tolerance: 1.0% Power: 63 mW PAckage:0402 | R152 | CRCW040254K9FKED
ERJ-3EKF6653V | 665K | Panasonic | 1 | 665 kOhm, ± 1%, 100 mW, 0603 [1608 Metric], Thick Film, Precision | R153 | ERJ-3EKF6653V
ERJ-3EKF51R1V | 51.1R | Panasonic | 1 | 51.1 Ohm 1% 0.1W(1/10W) ±100ppm/C Pad SMD T/R Automotive AEC-Q200 | R154 | ERJ-3EKF51R1V
ERJ-3EKF1303V | 130K | Panasonic | 1 | 130K Ohm 1% 0.1W Res Thick Film 0603 ±100ppm/°C Molded SMD Punched Carrier T/R | R155 | ERJ-3EKF1303V
ERJ-3EKF1022V | 10.2K | Panasonic | 1 | 10.2 kOhm, ± 1%, 100 mW, 0603 [1608 Metric], Thick Film, Precision | R156 | ERJ-3EKF1022V
ERJ-3EKF3742V | 37.4K | Panasonic | 1 | 37.4K Ohm 1% 1/10W ±100ppm/°C Molded SMD Punched Carrier T/R | R157 | ERJ-3EKF3742V
ERJ-3EKF1961V | 1.96K | Panasonic | 1 | 1.96K Ohm 1% 1/10W ±100ppm/°C Molded SMD Punched Carrier T/R | R158 | ERJ-3EKF1961V
ERJ-3EKF1241V | 1.24K | Panasonic | 1 | 1.24K Ohm 1% 1/10W 0603 | R168 | ERJ-3EKF1241V
103AT-2 | 103AT-2 |  | 1 | NTC Thermistor 10k Bead | RT1 | 103AT-2
S2B-PH-K-S | S2B-PH-K-S | JST | 1 | S2B-PH-K-S Header for PCB; pitch 2.00mm; 2-contacts; THT; male; side entry; 100V/2A | RTC_BAT | S2B-PH-K-S(LF)(SN)
5006 | CHARGE_TP |  | 1 | Test Point Compact THM PC .350 L .125 OD Heat Resistant Nylon 46 Black | Keystone Electronics 5006 | TP3 | 5006
5006 | Converter_TP |  | 1 | Test Point Compact THM PC .350 L .125 OD Heat Resistant Nylon 46 Black | Keystone Electronics 5006 | TP4 | 5006
5006 |  |  | 5 | Test Point Compact THM PC .350 L .125 OD Heat Resistant Nylon 46 Black | Keystone Electronics 5006 | TP_1V8, TP_3V3, TP_5V, TP_12V, TP_GND | 5006
2328702-6 | FPC_Connector_6P | TE Connectivity | 1 | FPC Connector; 0.5mm pitch dual contact back flip FPC, 6pos | TE Connectivity 2328702-6 | Trackpad | 2328702-6
TVS2200DRVR | TVS2200DRVR | Texas Instruments | 3 | ESD Suppressors / TVS Diodes 22V flat-clamp surge protection device 6-WSON -40 to 125 | U1, U7, U24 | TVS2200DRVR
SY6280AAC | SY6280AAC |  | 2 | 2.4V~5.5V 80mΩ Active High 1 High-side switch SOT-23-5 Power Distribution Switches ROHS | U2, U8 | SY6280AAC
FUSB302BMPX | FUSB302BMPX |  | 2 | USB Controller USB 3.1 USB Interface 14-MLP (2.5x2.5) | U3, U9 | FUSB302BMPX
TPD4E02B04DQAR | TPD4E02B04DQAR | Texas Instruments | 10 | TVS DIODE 3.6V 8.8V 10USON / 4-Channel ESD Protection Diode for USB Type-C and HDMI 2.0 | U4, U5, U6, U10, U11, U12, U14, U15, U18, U19 | TPD4E02B04DQAR
TPS22917LDBVR | TPS22917LDBVR | Texas Instruments | 1 | 5.5-V, 2-A, 80-mΩ , 10-nA leakage load switch adj. rise time and adj output discharge 6-SOT-23 -45 to 125 | U13 | TPS22917LDBVR
RT9193-33GB | RT9193-33GB | Richtek | 1 | RT9193 Series 300 mA 3.3 V Ultra-Low Noise Ultra-Fast CMOS LDO Regulator-SC-70-5 | U16 | RT9193-33GB
PI6C557-05BLE | PI6C557-05BLE | Diodes | 1 | Clock Generators & Support Products PCI express Gen 2 4 output clock gen | U17 | PI6C557-05BLE
TPS25750DRJK | TPS25750DRJK | Texas Instruments | 1 | USB Type-C and USB PD Controller with Integrated Power Switches Optimized for Power Applications | U25 | TPS25750DRJK
CAT24C256WI-GT3 | CAT24C256WI-GT3 |  | 1 | EEPROM Memory IC 256Kbit I2C 1 MHz 500 ns 8-SOIC | U26 | CAT24C256WI-GT3
BQ2579x | BQ25792RQM | Texas Instruments | 1 | BQ2579x HotRod | U27 | BQ25792RQM
292303-1 | USB_Ext_1 |  | 1 | USB-A (USB TYPE-A) USB 2.0 Receptacle Connector 4 Position Through Hole, Right Angle | USB1 | 292303-1
292303-1 | USB_Ext_2 |  | 1 | USB-A (USB TYPE-A) USB 2.0 Receptacle Connector 4 Position Through Hole, Right Angle | USB2 | 292303-1
Bus_M.2_Socket_E | Bus_M.2_Socket_E |  | 1 | PCIe M.2 Connectors, Storage and Server Connector, P=0.5mm, H=3.2mm, Key E,30Î¼in Au Plating | WIFI | MDT320E01001
ECS-250-8-37B2-RWY-TR | 25MHz/15PPM/8pF | ECS International | 1 | Crystal 25MHz ±15ppm (Tol) ±15ppm (Stability) 8pF FUND 50Ohm 4-Pin Mini-CSMD T/R | Y1 | ECS-250-8-37B2-RWY-TR
HCM4924000000ABJT | 24MHz/18pf/50Ohms | Citizen | 1 | Crystal 24MHz ±30ppm (Tol) ±50ppm (Stability) 18pF FUND 50Ohm Automotive 2-Pin HC-49/US SMD T/R | Y2 | HCM4924000000ABJT

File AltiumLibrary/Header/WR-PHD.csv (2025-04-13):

LIBRARYREFERENCE | FOOTPRINT1 | CATEGORY | COMMENT | COMPONENTLINK1DESCRIPTION | COMPONENTLINK1URL | COMPONENTLINK2DESCRIPTION | COMPONENTLINK2URL | CONTACT RESISTANCE | GENDER | MANUFACTURER | MANUFACTURER PART NUMBER | MATCH CODE | MOUNT | NUMBER OF PINS | NUMBER OF ROWS | OPERATING TEMPERATURE MAX | OPERATING TEMPERATURE MIN | ORIENTATION | PACKAGING | PITCH | RATED CURRENT | WITHSTANDING VOLTAGE | WORKING VOLTAGE | SHEETPART | DESIGNATOR | DESCRIPTION
61000411921 | 61000411921 | Board-to-Board Connectors | 61000411921 | Website Link | https://www.we-online.com/redexpert/article/61000411921?ad | Datasheet Link | https://www.we-online.com/redexpert/spec/61000411921?ad | 20mOhm | Socket Header | Wurth Elektronik | 61000411921 | WR-PHD | Surface Mount | 4 | 1 | 105°C | -40°C | Vertical | Tube | 2.54mm | 3A | 500V | 250V | * | J? | WR-PHD Socket Header, SMT, Vertical, pitch 2.54mm, 1 Row, 4P
61000413321 | 61000413321 | Board-to-Board Connectors | 61000413321 | Website Link | https://www.we-online.com/redexpert/article/61000413321?ad | Datasheet Link | https://www.we-online.com/redexpert/spec/61000413321?ad | 20mOhm | Socket Header | Wurth Elektronik | 61000413321 | WR-PHD | Surface Mount | 4 | 1 | 125°C | -40°C | Vertical | Tube | 2.54mm | 3A | 500V | 250V | * | J? | WR-PHD Socket Header, SMT, Vertical, pitch 2.54mm, 1 Row, 4P
61000418221 | 61000418221 | Board-to-Board Connectors | 61000418221 | Website Link | https://www.we-online.com/redexpert/article/61000418221?ad | Datasheet Link | https://www.we-online.com/redexpert/spec/61000418221?ad | 20mOhm | Pin Header | Wurth Elektronik | 61000418221 | WR-PHD | Surface Mount | 4 | 1 | 105°C | -40°C | Vertical | Tube | 2.54mm | 3A | 500V | 250V | * | P? | WR-PHD Pin Header, SMT, Vertical, pitch 2.54mm, 1 Row, 4P
61000418321 | 61000418321 | Board-to-Board Connectors | 61000418321 | Website Link | https://www.we-online.com/redexpert/article/61000418321?ad | Datasheet Link | https://www.we-online.com/redexpert/spec/61000418321?ad | 20mOhm | Pin Header | Wurth Elektronik | 61000418321 | WR-PHD | Surface Mount | 4 | 1 | 125°C | -40°C | Vertical | Tube | 2.54mm | 3A | 500V | 250V | * | P? | WR-PHD Pin Header, SMT, Vertical, pitch 2.54mm, 1 Row, 4P
61000421121 | 61000421121 | Board-to-Board Connectors | 61000421121 | Website Link | https://www.we-online.com/redexpert/article/61000421121?ad | Datasheet Link | https://www.we-online.com/redexpert/spec/61000421121?ad | 20mOhm | Pin Header | Wurth Elektronik | 61000421121 | WR-PHD | Surface Mount | 4 | 2 | 125°C | -40°C | Vertical | Tube | 2.54mm | 3A | 500V | 250V | * | P? | WR-PHD Pin Header, SMT, Vertical, pitch 2.54mm, 2 Row, 4P
61000421821 | 61000421821 | Board-to-Board Connectors | 61000421821 | Website Link | https://www.we-online.com/redexpert/article/61000421821?ad | Datasheet Link | https://www.we-online.com/redexpert/spec/61000421821?ad | 20mOhm | Socket Header | Wurth Elektronik | 61000421821 | WR-PHD | Surface Mount | 4 | 2 | 105°C | -40°C | Vertical | Tube | 2.54mm | 3A | 600V | 250V | * | J? | WR-PHD Socket Header, SMT, Vertical, pitch 2.54mm, 2 Row, 4P
610004243021 | 610004243021 | Board-to-Board Connectors | 610004243021 | Website Link | https://www.we-online.com/redexpert/article/610004243021?ad | Datasheet Link | https://www.we-online.com/redexpert/spec/610004243021?ad | 20mOhm | Socket Header | Wurth Elektronik | 610004243021 | WR-PHD | Surface Mount | 4 | 2 | 125°C | -40°C | Vertical | Tube | 2.54mm | 3A | 500V | 250V | * | J? | WR-PHD Socket Header, SMT, Vertical, pitch 2.54mm, 2 Row, 4P
61000511921 | 61000511921 | Board-to-Board Connectors | 61000511921 | Website Link | https://www.we-online.com/redexpert/article/61000511921?ad | Datasheet Link | https://www.we-online.com/redexpert/spec/61000511921?ad | 20mOhm | Socket Header | Wurth Elektronik | 61000511921 | WR-PHD | Surface Mount | 5 | 1 | 105°C | -40°C | Vertical | Tube | 2.54mm | 3A | 500V | 250V | * | J? | WR-PHD Socket Header, SMT, Vertical, pitch 2.54mm, 1 Row, 5P
61000513321 | 61000513321 | Board-to-Board Connectors | 61000513321 | Website Link | https://www.we-online.com/redexpert/article/61000513321?ad | Datasheet Link | https://www.we-online.com/redexpert/spec/61000513321?ad | 20mOhm | Socket Header | Wurth Elektronik | 61000513321 | WR-PHD | Surface Mount | 5 | 1 | 125°C | -40°C | Vertical | Tube | 2.54mm | 3A | 500V | 250V | * | J? | WR-PHD Socket Header, SMT, Vertical, pitch 2.54mm, 1 Row, 5P
61000611921 | 61000611921 | Board-to-Board Connectors | 61000611921 | Website Link | https://www.we-online.com/redexpert/article/61000611921?ad | Datasheet Link | https://www.we-online.com/redexpert/spec/61000611921?ad | 20mOhm | Socket Header | Wurth Elektronik | 61000611921 | WR-PHD | Surface Mount | 6 | 1 | 105°C | -40°C | Vertical | Tube | 2.54mm | 3A | 500V | 250V | * | J? | WR-PHD Socket Header, SMT, Vertical, pitch 2.54mm, 1 Row, 6P
61000613321 | 61000613321 | Board-to-Board Connectors | 61000613321 | Website Link | https://www.we-online.com/redexpert/article/61000613321?ad | Datasheet Link | https://www.we-online.com/redexpert/spec/61000613321?ad | 20mOhm | Socket Header | Wurth Elektronik | 61000613321 | WR-PHD | Surface Mount | 6 | 1 | 125°C | -40°C | Vertical | Tube | 2.54mm | 3A | 500V | 250V | * | J? | WR-PHD Socket Header, SMT, Vertical, pitch 2.54mm, 1 Row, 6P
61000618221 | 61000618221 | Board-to-Board Connectors | 61000618221 | Website Link | https://www.we-online.com/redexpert/article/61000618221?ad | Datasheet Link | https://www.we-online.com/redexpert/spec/61000618221?ad | 20mOhm | Pin Header | Wurth Elektronik | 61000618221 | WR-PHD | Surface Mount | 6 | 1 | 105°C | -40°C | Vertical | Tube | 2.54mm | 3A | 500V | 250V | * | P? | WR-PHD Pin Header, SMT, Vertical, pitch 2.54mm, 1 Row, 6P
61000618321 | 61000618321 | Board-to-Board Connectors | 61000618321 | Website Link | https://www.we-online.com/redexpert/article/61000618321?ad | Datasheet Link | https://www.we-online.com/redexpert/spec/61000618321?ad | 20mOhm | Pin Header | Wurth Elektronik | 61000618321 | WR-PHD | Surface Mount | 6 | 1 | 125°C | -40°C | Vertical | Tube | 2.54mm | 3A | 500V | 250V | * | P? | WR-PHD Pin Header, SMT, Vertical, pitch 2.54mm, 1 Row, 6P
61000621121 | 61000621121 | Board-to-Board Connectors | 61000621121 | Website Link | https://www.we-online.com/redexpert/article/61000621121?ad | Datasheet Link | https://www.we-online.com/redexpert/spec/61000621121?ad | 20mOhm | Pin Header | Wurth Elektronik | 61000621121 | WR-PHD | Surface Mount | 6 | 2 | 125°C | -40°C | Vertical | Tube | 2.54mm | 3A | 500V | 250V | * | P? | WR-PHD Pin Header, SMT, Vertical, pitch 2.54mm, 2 Row, 6P
61000621821 | 61000621821 | Board-to-Board Connectors | 61000621821 | Website Link | https://www.we-online.com/redexpert/article/61000621821?ad | Datasheet Link | https://www.we-online.com/redexpert/spec/61000621821?ad | 20mOhm | Socket Header | Wurth Elektronik | 61000621821 | WR-PHD | Surface Mount | 6 | 2 | 105°C | -40°C | Vertical | Tube | 2.54mm | 3A | 600V | 250V | * | J? | WR-PHD Socket Header, SMT, Vertical, pitch 2.54mm, 2 Row, 6P
610006243021 | 610006243021 | Board-to-Board Connectors | 610006243021 | Website Link | https://www.we-online.com/redexpert/article/610006243021?ad | Datasheet Link | https://www.we-online.com/redexpert/spec/610006243021?ad | 20mOhm | Socket Header | Wurth Elektronik | 610006243021 | WR-PHD | Surface Mount | 6 | 2 | 125°C | -40°C | Vertical | Tube | 2.54mm | 3A | 500V | 250V | * | J? | WR-PHD Socket Header, SMT, Vertical, pitch 2.54mm, 2 Row, 6P
61000811921 | 61000811921 | Board-to-Board Connectors | 61000811921 | Website Link | https://www.we-online.com/redexpert/article/61000811921?ad | Datasheet Link | https://www.we-online.com/redexpert/spec/61000811921?ad | 20mOhm | Socket Header | Wurth Elektronik | 61000811921 | WR-PHD | Surface Mount | 8 | 1 | 105°C | -40°C | Vertical | Tube | 2.54mm | 3A | 500V | 250V | * | J? | WR-PHD Socket Header, SMT, Vertical, pitch 2.54mm, 1 Row, 8P
61000813321 | 61000813321 | Board-to-Board Connectors | 61000813321 | Website Link | https://www.we-online.com/redexpert/article/61000813321?ad | Datasheet Link | https://www.we-online.com/redexpert/spec/61000813321?ad | 20mOhm | Socket Header | Wurth Elektronik | 61000813321 | WR-PHD | Surface Mount | 8 | 1 | 105°C | -40°C | Vertical | Tube | 2.54mm | 3A | 500V | 250V | * | J? | WR-PHD Socket Header, SMT, Vertical, pitch 2.54mm, 1 Row, 8P
61000821121 | 61000821121 | Board-to-Board Connectors | 61000821121 | Website Link | https://www.we-online.com/redexpert/article/61000821121?ad | Datasheet Link | https://www.we-online.com/redexpert/spec/61000821121?ad | 20mOhm | Pin Header | Wurth Elektronik | 61000821121 | WR-PHD | Surface Mount | 8 | 2 | 125°C | -40°C | Vertical | Tube | 2.54mm | 3A | 500V | 250V | * | P? | WR-PHD Pin Header, SMT, Vertical, pitch 2.54mm, 2 Row, 8P
61000821821 | 61000821821 | Board-to-Board Connectors | 61000821821 | Website Link | https://www.we-online.com/redexpert/article/61000821821?ad | Datasheet Link | https://www.we-online.com/redexpert/spec/61000821821?ad | 20mOhm | Socket Header | Wurth Elektronik | 61000821821 | WR-PHD | Surface Mount | 8 | 2 | 105°C | -40°C | Vertical | Tube | 2.54mm | 3A | 600V | 250V | * | J? | WR-PHD Socket Header, SMT, Vertical, pitch 2.54mm, 2 Row, 8P
610008243021 | 610008243021 | Board-to-Board Connectors | 610008243021 | Website Link | https://www.we-online.com/redexpert/article/610008243021?ad | Datasheet Link | https://www.we-online.com/redexpert/spec/610008243021?ad | 20mOhm | Socket Header | Wurth Elektronik | 610008243021 | WR-PHD | Surface Mount | 8 | 2 | 125°C | -40°C | Vertical | Tube | 2.54mm | 3A | 500V | 250V | * | J? | WR-PHD Socket Header, SMT, Vertical, pitch 2.54mm, 2 Row, 8P
61001011921 | 61001011921 | Board-to-Board Connectors | 61001011921 | Website Link | https://www.we-online.com/redexpert/article/61001011921?ad | Datasheet Link | https://www.we-online.com/redexpert/spec/61001011921?ad | 20mOhm | Socket Header | Wurth Elektronik | 61001011921 | WR-PHD | Surface Mount | 10 | 1 | 105°C | -40°C | Vertical | Tube | 2.54mm | 3A | 500V | 250V | * | J? | WR-PHD Socket Header, SMT, Vertical, pitch 2.54mm, 1 Row, 10P
61001013321 | 61001013321 | Board-to-Board Connectors | 61001013321 | Website Link | https://www.we-online.com/redexpert/article/61001013321?ad | Datasheet Link | https://www.we-online.com/redexpert/spec/61001013321?ad | 20mOhm | Socket Header | Wurth Elektronik | 61001013321 | WR-PHD | Surface Mount | 10 | 1 | 105°C | -40°C | Vertical | Tube | 2.54mm | 3A | 500V | 250V | * | J? | WR-PHD Socket Header, SMT, Vertical, pitch 2.54mm, 1 Row, 10P
61001018221 | 61001018221 | Board-to-Board Connectors | 61001018221 | Website Link | https://www.we-online.com/redexpert/article/61001018221?ad | Datasheet Link | https://www.we-online.com/redexpert/spec/61001018221?ad | 20mOhm | Pin Header | Wurth Elektronik | 61001018221 | WR-PHD | Surface Mount | 10 | 1 | 105°C | -40°C | Vertical | Tube | 2.54mm | 3A | 500V | 250V | * | P? | WR-PHD Pin Header, SMT, Vertical, pitch 2.54mm, 1 Row, 10P
61001018321 | 61001018321 | Board-to-Board Connectors | 61001018321 | Website Link | https://www.we-online.com/redexpert/article/61001018321?ad | Datasheet Link | https://www.we-online.com/redexpert/spec/61001018321?ad | 20mOhm | Pin Header | Wurth Elektronik | 61001018321 | WR-PHD | Surface Mount | 10 | 1 | 125°C | -40°C | Vertical | Tube | 2.54mm | 3A | 500V | 250V | * | P? | WR-PHD Pin Header, SMT, Vertical, pitch 2.54mm, 1 Row, 10P
61001021121 | 61001021121 | Board-to-Board Connectors | 61001021121 | Website Link | https://www.we-online.com/redexpert/article/61001021121?ad | Datasheet Link | https://www.we-online.com/redexpert/spec/61001021121?ad | 20mOhm | Pin Header | Wurth Elektronik | 61001021121 | WR-PHD | Surface Mount | 10 | 2 | 125°C | -40°C | Vertical | Tube | 2.54mm | 3A | 500V | 250V | * | P? | WR-PHD Pin Header, SMT, Vertical, pitch 2.54mm, 2 Row, 10P
61001021821 | 61001021821 | Board-to-Board Connectors | 61001021821 | Website Link | https://www.we-online.com/redexpert/article/61001021821?ad | Datasheet Link | https://www.we-online.com/redexpert/spec/61001021821?ad | 20mOhm | Socket Header | Wurth Elektronik | 61001021821 | WR-PHD | Surface Mount | 10 | 2 | 105°C | -40°C | Vertical | Tube | 2.54mm | 3A | 600V | 250V | * | J? | WR-PHD Socket Header, SMT, Vertical, pitch 2.54mm, 2 Row, 10P
610010243021 | 610010243021 | Board-to-Board Connectors | 610010243021 | Website Link | https://www.we-online.com/redexpert/article/610010243021?ad | Datasheet Link | https://www.we-online.com/redexpert/spec/610010243021?ad | 20mOhm | Socket Header | Wurth Elektronik | 610010243021 | WR-PHD | Surface Mount | 10 | 2 | 125°C | -40°C | Vertical | Tube | 2.54mm | 3A | 500V | 250V | * | J? | WR-PHD Socket Header, SMT, Vertical, pitch 2.54mm, 2 Row, 10P
61001211921 | 61001211921 | Board-to-Board Connectors | 61001211921 | Website Link | https://www.we-online.com/redexpert/article/61001211921?ad | Datasheet Link | https://www.we-online.com/redexpert/spec/61001211921?ad | 20mOhm | Socket Header | Wurth Elektronik | 61001211921 | WR-PHD | Surface Mount | 12 | 1 | 105°C | -40°C | Vertical | Tube | 2.54mm | 3A | 500V | 250V | * | J? | WR-PHD Socket Header, SMT, Vertical, pitch 2.54mm, 1 Row, 12P
61001213321 | 61001213321 | Board-to-Board Connectors | 61001213321 | Website Link | https://www.we-online.com/redexpert/article/61001213321?ad | Datasheet Link | https://www.we-online.com/redexpert/spec/61001213321?ad | 20mOhm | Socket Header | Wurth Elektronik | 61001213321 | WR-PHD | Surface Mount | 12 | 1 | 105°C | -40°C | Vertical | Tube | 2.54mm | 3A | 500V | 250V | * | J? | WR-PHD Socket Header, SMT, Vertical, pitch 2.54mm, 1 Row, 12P
61001221121 | 61001221121 | Board-to-Board Connectors | 61001221121 | Website Link | https://www.we-online.com/redexpert/article/61001221121?ad | Datasheet Link | https://www.we-online.com/redexpert/spec/61001221121?ad | 20mOhm | Pin Header | Wurth Elektronik | 61001221121 | WR-PHD | Surface Mount | 12 | 2 | 125°C | -40°C | Vertical | Tube | 2.54mm | 3A | 500V | 250V | * | P? | WR-PHD Pin Header, SMT, Vertical, pitch 2.54mm, 2 Row, 12P
61001221821 | 61001221821 | Board-to-Board Connectors | 61001221821 | Website Link | https://www.we-online.com/redexpert/article/61001221821?ad | Datasheet Link | https://www.we-online.com/redexpert/spec/61001221821?ad | 20mOhm | Socket Header | Wurth Elektronik | 61001221821 | WR-PHD | Surface Mount | 12 | 2 | 105°C | -40°C | Vertical | Tube | 2.54mm | 3A | 600V | 250V | * | J? | WR-PHD Socket Header, SMT, Vertical, pitch 2.54mm, 2 Row, 12P
610012243021 | 610012243021 | Board-to-Board Connectors | 610012243021 | Website Link | https://www.we-online.com/redexpert/article/610012243021?ad | Datasheet Link | https://www.we-online.com/redexpert/spec/610012243021?ad | 20mOhm | Socket Header | Wurth Elektronik | 610012243021 | WR-PHD | Surface Mount | 12 | 2 | 125°C | -40°C | Vertical | Tube | 2.54mm | 3A | 500V | 250V | * | J? | WR-PHD Socket Header, SMT, Vertical, pitch 2.54mm, 2 Row, 12P
61001413321 | 61001413321 | Board-to-Board Connectors | 61001413321 | Website Link | https://www.we-online.com/redexpert/article/61001413321?ad | Datasheet Link | https://www.we-online.com/redexpert/spec/61001413321?ad | 20mOhm | Socket Header | Wurth Elektronik | 61001413321 | WR-PHD | Surface Mount | 14 | 1 | 105°C | -40°C | Vertical | Tube | 2.54mm | 3A | 500V | 250V | * | J? | WR-PHD Socket Header, SMT, Vertical, pitch 2.54mm, 1 Row, 14P
61001418221 | 61001418221 | Board-to-Board Connectors | 61001418221 | Website Link | https://www.we-online.com/redexpert/article/61001418221?ad | Datasheet Link | https://www.we-online.com/redexpert/spec/61001418221?ad | 20mOhm | Pin Header | Wurth Elektronik | 61001418221 | WR-PHD | Surface Mount | 14 | 1 | 105°C | -40°C | Vertical | Tube | 2.54mm | 3A | 500V | 250V | * | P? | WR-PHD Pin Header, SMT, Vertical, pitch 2.54mm, 1 Row, 14P
61001421121 | 61001421121 | Board-to-Board Connectors | 61001421121 | Website Link | https://www.we-online.com/redexpert/article/61001421121?ad | Datasheet Link | https://www.we-online.com/redexpert/spec/61001421121?ad | 20mOhm | Pin Header | Wurth Elektronik | 61001421121 | WR-PHD | Surface Mount | 14 | 2 | 125°C | -40°C | Vertical | Tube | 2.54mm | 3A | 500V | 250V | * | P? | WR-PHD Pin Header, SMT, Vertical, pitch 2.54mm, 2 Row, 14P
61001421821 | 61001421821 | Board-to-Board Connectors | 61001421821 | Website Link | https://www.we-online.com/redexpert/article/61001421821?ad | Datasheet Link | https://www.we-online.com/redexpert/spec/61001421821?ad | 20mOhm | Socket Header | Wurth Elektronik | 61001421821 | WR-PHD | Surface Mount | 14 | 2 | 105°C | -40°C | Vertical | Tube | 2.54mm | 3A | 600V | 250V | * | J? | WR-PHD Socket Header, SMT, Vertical, pitch 2.54mm, 2 Row, 14P
61001511921 | 61001511921 | Board-to-Board Connectors | 61001511921 | Website Link | https://www.we-online.com/redexpert/article/61001511921?ad | Datasheet Link | https://www.we-online.com/redexpert/spec/61001511921?ad | 20mOhm | Socket Header | Wurth Elektronik | 61001511921 | WR-PHD | Surface Mount | 15 | 1 | 105°C | -40°C | Vertical | Tube | 2.54mm | 3A | 500V | 250V | * | J? | WR-PHD Socket Header, SMT, Vertical, pitch 2.54mm, 1 Row, 15P
61001513321 | 61001513321 | Board-to-Board Connectors | 61001513321 | Website Link | https://www.we-online.com/redexpert/article/61001513321?ad | Datasheet Link | https://www.we-online.com/redexpert/spec/61001513321?ad | 20mOhm | Socket Header | Wurth Elektronik | 61001513321 | WR-PHD | Surface Mount | 15 | 1 | 105°C | -40°C | Vertical | Tube | 2.54mm | 3A | 500V | 250V | * | J? | WR-PHD Socket Header, SMT, Vertical, pitch 2.54mm, 1 Row, 15P
61001518221 | 61001518221 | Board-to-Board Connectors | 61001518221 | Website Link | https://www.we-online.com/redexpert/article/61001518221?ad | Datasheet Link | https://www.we-online.com/redexpert/spec/61001518221?ad | 20mOhm | Pin Header | Wurth Elektronik | 61001518221 | WR-PHD | Surface Mount | 15 | 1 | 105°C | -40°C | Vertical | Tube | 2.54mm | 3A | 500V | 250V | * | P? | WR-PHD Pin Header, SMT, Vertical, pitch 2.54mm, 1 Row, 15P
61001611921 | 61001611921 | Board-to-Board Connectors | 61001611921 | Website Link | https://www.we-online.com/redexpert/article/61001611921?ad | Datasheet Link | https://www.we-online.com/redexpert/spec/61001611921?ad | 20mOhm | Socket Header | Wurth Elektronik | 61001611921 | WR-PHD | Surface Mount | 16 | 1 | 105°C | -40°C | Vertical | Tube | 2.54mm | 3A | 500V | 250V | * | J? | WR-PHD Socket Header, SMT, Vertical, pitch 2.54mm, 1 Row, 16P
61001613321 | 61001613321 | Board-to-Board Connectors | 61001613321 | Website Link | https://www.we-online.com/redexpert/article/61001613321?ad | Datasheet Link | https://www.we-online.com/redexpert/spec/61001613321?ad | 20mOhm | Socket Header | Wurth Elektronik | 61001613321 | WR-PHD | Surface Mount | 16 | 1 | 105°C | -40°C | Vertical | Tube | 2.54mm | 3A | 500V | 250V | * | J? | WR-PHD Socket Header, SMT, Vertical, pitch 2.54mm, 1 Row, 16P
61001618221 | 61001618221 | Board-to-Board Connectors | 61001618221 | Website Link | https://www.we-online.com/redexpert/article/61001618221?ad | Datasheet Link | https://www.we-online.com/redexpert/spec/61001618221?ad | 20mOhm | Pin Header | Wurth Elektronik | 61001618221 | WR-PHD | Surface Mount | 16 | 1 | 105°C | -40°C | Vertical | Tube | 2.54mm | 3A | 500V | 250V | * | P? | WR-PHD Pin Header, SMT, Vertical, pitch 2.54mm, 1 Row, 16P
61001618321 | 61001618321 | Board-to-Board Connectors | 61001618321 | Website Link | https://www.we-online.com/redexpert/article/61001618321?ad | Datasheet Link | https://www.we-online.com/redexpert/spec/61001618321?ad | 20mOhm | Pin Header | Wurth Elektronik | 61001618321 | WR-PHD | Surface Mount | 16 | 1 | 125°C | -40°C | Vertical | Tube | 2.54mm | 3A | 500V | 250V | * | P? | WR-PHD Pin Header, SMT, Vertical, pitch 2.54mm, 1 Row, 16P
61001621121 | 61001621121 | Board-to-Board Connectors | 61001621121 | Website Link | https://www.we-online.com/redexpert/article/61001621121?ad | Datasheet Link | https://www.we-online.com/redexpert/spec/61001621121?ad | 20mOhm | Pin Header | Wurth Elektronik | 61001621121 | WR-PHD | Surface Mount | 16 | 2 | 125°C | -40°C | Vertical | Tube | 2.54mm | 3A | 500V | 250V | * | P? | WR-PHD Pin Header, SMT, Vertical, pitch 2.54mm, 2 Row, 16P
61001621821 | 61001621821 | Board-to-Board Connectors | 61001621821 | Website Link | https://www.we-online.com/redexpert/article/61001621821?ad | Datasheet Link | https://www.we-online.com/redexpert/spec/61001621821?ad | 20mOhm | Socket Header | Wurth Elektronik | 61001621821 | WR-PHD | Surface Mount | 16 | 2 | 105°C | -40°C | Vertical | Tube | 2.54mm | 3A | 600V | 250V | * | J? | WR-PHD Socket Header, SMT, Vertical, pitch 2.54mm, 2 Row, 16P
610016243021 | 610016243021 | Board-to-Board Connectors | 610016243021 | Website Link | https://www.we-online.com/redexpert/article/610016243021?ad | Datasheet Link | https://www.we-online.com/redexpert/spec/610016243021?ad | 20mOhm | Socket Header | Wurth Elektronik | 610016243021 | WR-PHD | Surface Mount | 16 | 2 | 125°C | -40°C | Vertical | Tube | 2.54mm | 3A | 500V | 250V | * | J? | WR-PHD Socket Header, SMT, Vertical, pitch 2.54mm, 2 Row, 16P
61001821821 | 61001821821 | Board-to-Board Connectors | 61001821821 | Website Link | https://www.we-online.com/redexpert/article/61001821821?ad | Datasheet Link | https://www.we-online.com/redexpert/spec/61001821821?ad | 20mOhm | Socket Header | Wurth Elektronik | 61001821821 | WR-PHD | Surface Mount | 18 | 2 | 105°C | -40°C | Vertical | Tube | 2.54mm | 3A | 600V | 250V | * | J? | WR-PHD Socket Header, SMT, Vertical, pitch 2.54mm, 2 Row, 18P
610018243021 | 610018243021 | Board-to-Board Connectors | 610018243021 | Website Link | https://www.we-online.com/redexpert/article/610018243021?ad | Datasheet Link | https://www.we-online.com/redexpert/spec/610018243021?ad | 20mOhm | Socket Header | Wurth Elektronik | 610018243021 | WR-PHD | Surface Mount | 18 | 2 | 125°C | -40°C | Vertical | Tube | 2.54mm | 3A | 500V | 250V | * | J? | WR-PHD Socket Header, SMT, Vertical, pitch 2.54mm, 2 Row, 18P
61002011921 | 61002011921 | Board-to-Board Connectors | 61002011921 | Website Link | https://www.we-online.com/redexpert/article/61002011921?ad | Datasheet Link | https://www.we-online.com/redexpert/spec/61002011921?ad | 20mOhm | Socket Header | Wurth Elektronik | 61002011921 | WR-PHD | Surface Mount | 20 | 1 | 105°C | -40°C | Vertical | Tube | 2.54mm | 3A | 500V | 250V | * | J? | WR-PHD Socket Header, SMT, Vertical, pitch 2.54mm, 1 Row, 20P
61002013321 | 61002013321 | Board-to-Board Connectors | 61002013321 | Website Link | https://www.we-online.com/redexpert/article/61002013321?ad | Datasheet Link | https://www.we-online.com/redexpert/spec/61002013321?ad | 20mOhm | Socket Header | Wurth Elektronik | 61002013321 | WR-PHD | Surface Mount | 20 | 1 | 105°C | -40°C | Vertical | Tube | 2.54mm | 3A | 500V | 250V | * | J? | WR-PHD Socket Header, SMT, Vertical, pitch 2.54mm, 1 Row, 20P
61002021121 | 61002021121 | Board-to-Board Connectors | 61002021121 | Website Link | https://www.we-online.com/redexpert/article/61002021121?ad | Datasheet Link | https://www.we-online.com/redexpert/spec/61002021121?ad | 20mOhm | Pin Header | Wurth Elektronik | 61002021121 | WR-PHD | Surface Mount | 20 | 2 | 125°C | -40°C | Vertical | Tube | 2.54mm | 3A | 500V | 250V | * | P? | WR-PHD Pin Header, SMT, Vertical, pitch 2.54mm, 2 Row, 20P
61002021821 | 61002021821 | Board-to-Board Connectors | 61002021821 | Website Link | https://www.we-online.com/redexpert/article/61002021821?ad | Datasheet Link | https://www.we-online.com/redexpert/spec/61002021821?ad | 20mOhm | Socket Header | Wurth Elektronik | 61002021821 | WR-PHD | Surface Mount | 20 | 2 | 105°C | -40°C | Vertical | Tube | 2.54mm | 3A | 600V | 250V | * | J? | WR-PHD Socket Header, SMT, Vertical, pitch 2.54mm, 2 Row, 20P
610020243021 | 610020243021 | Board-to-Board Connectors | 610020243021 | Website Link | https://www.we-online.com/redexpert/article/610020243021?ad | Datasheet Link | https://www.we-online.com/redexpert/spec/610020243021?ad | 20mOhm | Socket Header | Wurth Elektronik | 610020243021 | WR-PHD | Surface Mount | 20 | 2 | 125°C | -40°C | Vertical | Tube | 2.54mm | 3A | 500V | 250V | * | J? | WR-PHD Socket Header, SMT, Vertical, pitch 2.54mm, 2 Row, 20P
61002221121 | 61002221121 | Board-to-Board Connectors | 61002221121 | Website Link | https://www.we-online.com/redexpert/article/61002221121?ad | Datasheet Link | https://www.we-online.com/redexpert/spec/61002221121?ad | 20mOhm | Pin Header | Wurth Elektronik | 61002221121 | WR-PHD | Surface Mount | 22 | 2 | 125°C | -40°C | Vertical | Tube | 2.54mm | 3A | 500V | 250V | * | P? | WR-PHD Pin Header, SMT, Vertical, pitch 2.54mm, 2 Row, 22P
61002221821 | 61002221821 | Board-to-Board Connectors | 61002221821 | Website Link | https://www.we-online.com/redexpert/article/61002221821?ad | Datasheet Link | https://www.we-online.com/redexpert/spec/61002221821?ad | 20mOhm | Socket Header | Wurth Elektronik | 61002221821 | WR-PHD | Surface Mount | 22 | 2 | 105°C | -40°C | Vertical | Tube | 2.54mm | 3A | 600V | 250V | * | J? | WR-PHD Socket Header, SMT, Vertical, pitch 2.54mm, 2 Row, 22P
610022243021 | 610022243021 | Board-to-Board Connectors | 610022243021 | Website Link | https://www.we-online.com/redexpert/article/610022243021?ad | Datasheet Link | https://www.we-online.com/redexpert/spec/610022243021?ad | 20mOhm | Socket Header | Wurth Elektronik | 610022243021 | WR-PHD | Surface Mount | 22 | 2 | 125°C | -40°C | Vertical | Tube | 2.54mm | 3A | 500V | 250V | * | J? | WR-PHD Socket Header, SMT, Vertical, pitch 2.54mm, 2 Row, 22P
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

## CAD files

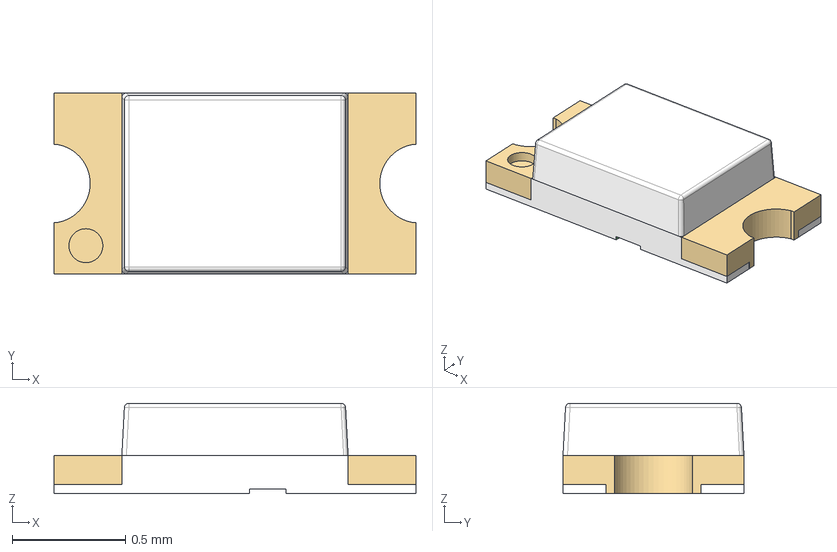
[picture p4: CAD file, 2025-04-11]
Librairy/0603_LED/Download_STP_WL-WL-SMCD-0603_rev1.stp
1.60 x 0.8 x 0.4 mm
housing
cover
base-oa0
base

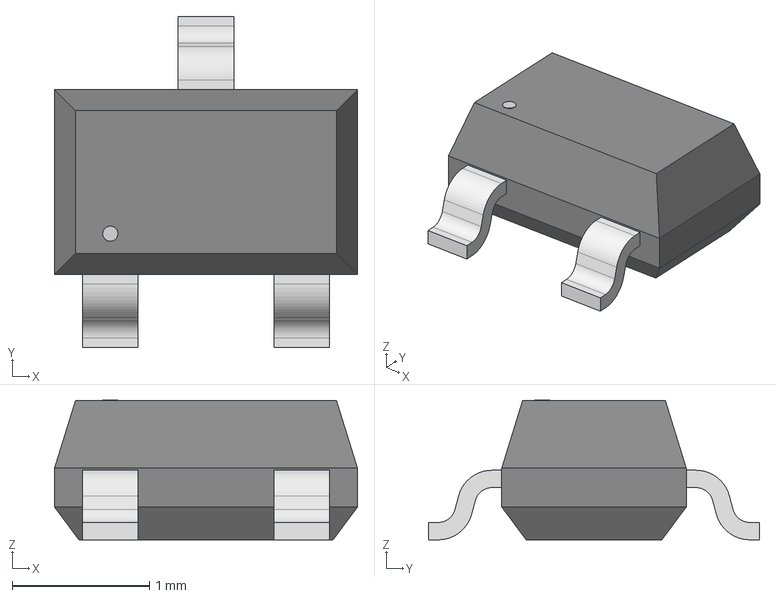
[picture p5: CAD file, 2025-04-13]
Librairy/2N7002WT1G/SOT-323-3_2P2X1P35_ONS.step
2.21 x 2.41 x 1.02 mm

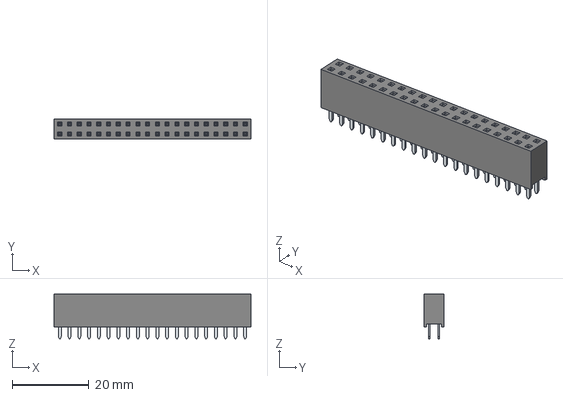
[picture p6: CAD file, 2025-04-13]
Librairy/2X20_POSITION_HEADER_FEMALE/Download_STP_61304021821_rev1.stp
51.3 x 5.08 x 11.6 mm
6130xx21821_PIN x 40

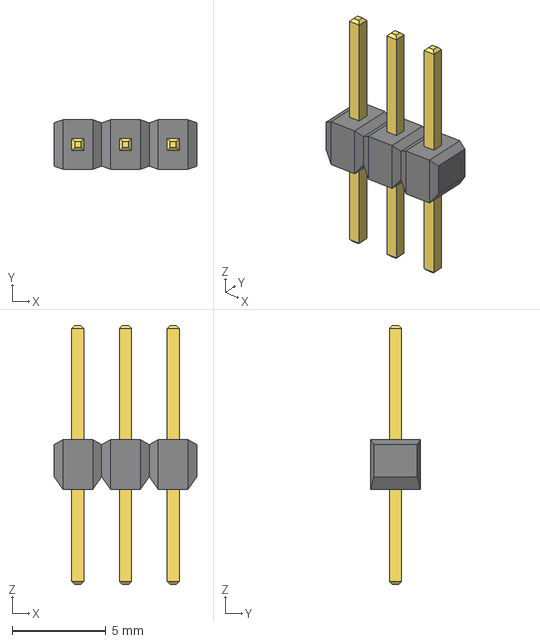
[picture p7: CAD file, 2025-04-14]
Librairy/3_pin_male_header/AltiumDesigner/CONN_M20-99903XX_HRW.step
7.62 x 2.64 x 13.8 mm

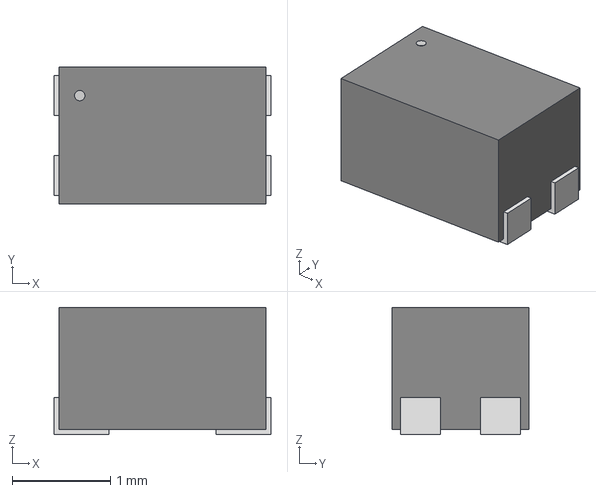
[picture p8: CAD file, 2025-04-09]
Librairy/ACM2012_900_2P_T002/ACM2012_TDK.step
2.21 x 1.40 x 1.30 mm

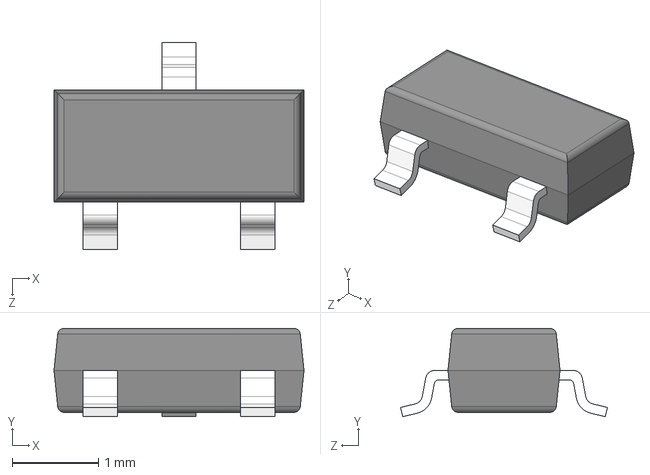
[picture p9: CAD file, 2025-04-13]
Librairy/AP2331TDSA-7/AP2331TDSA-7/3D/AP2331TDSA-7.stp
2.90 x 1.02 x 2.40 mm

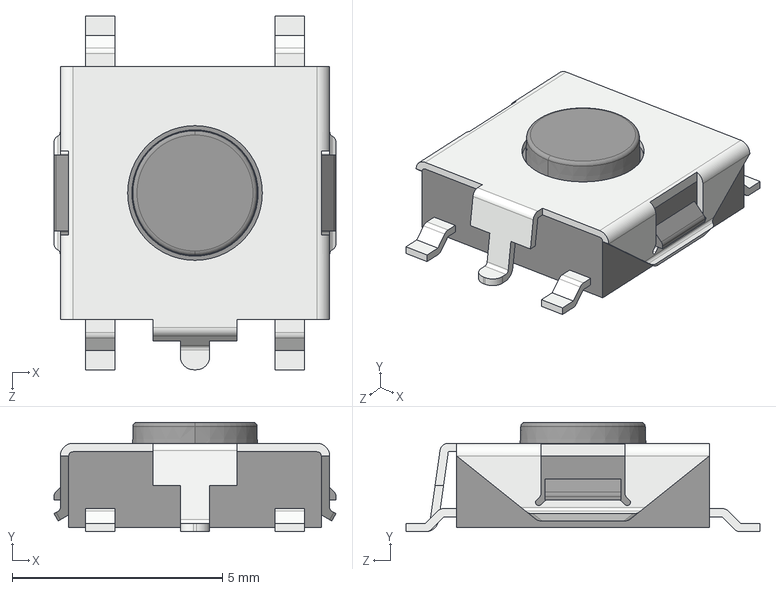
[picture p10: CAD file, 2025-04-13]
Librairy/btn_SMD/TS06-667-25-BK-100-G-SMT-TR.STEP
6.70 x 2.60 x 8.40 mm

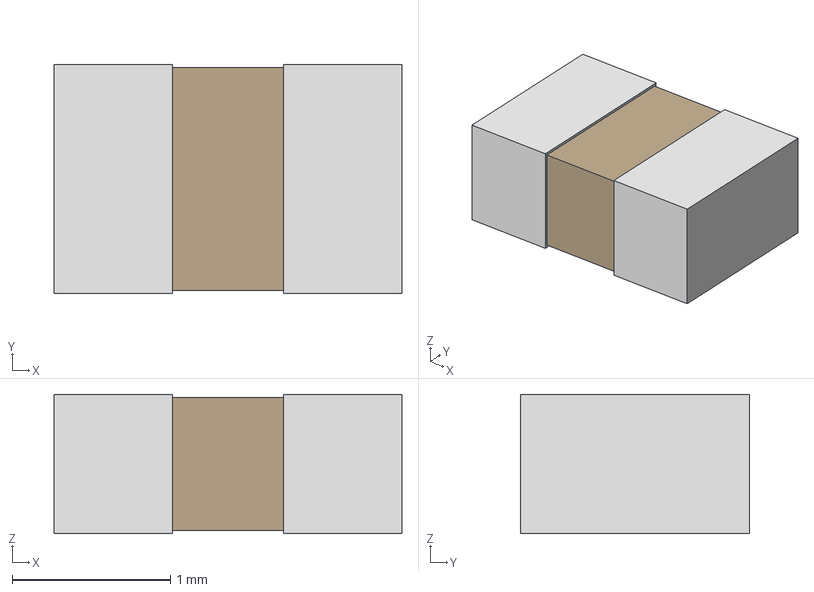
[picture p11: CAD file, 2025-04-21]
Librairy/C0805C103K5RACTU/AltiumDesigner/CAPC220145_88N_KEM.step
2.20 x 1.45 x 0.88 mm

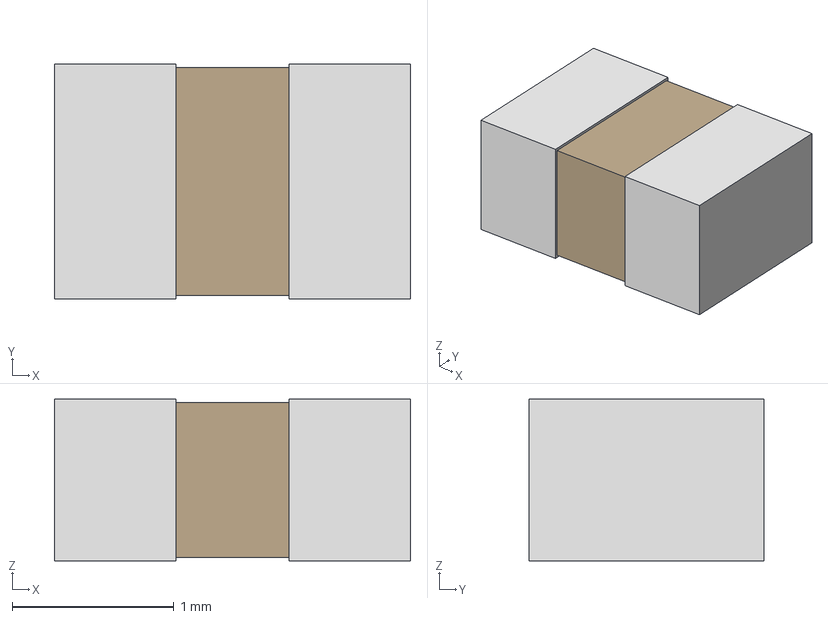
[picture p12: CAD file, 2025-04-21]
Librairy/C0805C105K8RACTU/CAPC220145_100N_KEM.step
2.20 x 1.45 x 1.00 mm

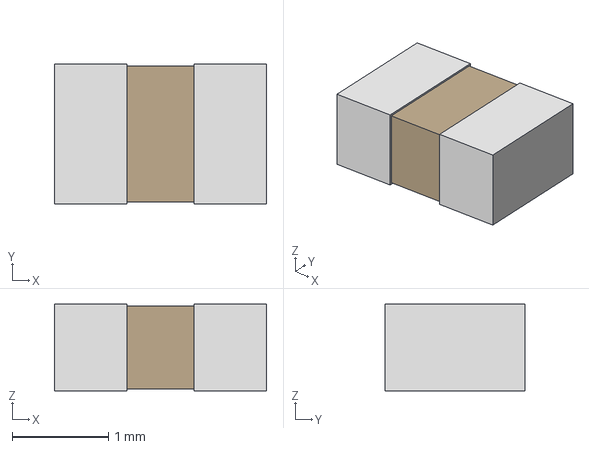
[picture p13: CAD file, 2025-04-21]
Librairy/C0805C220J5RACTU/CAPC220145_90N_KEM.step
2.20 x 1.45 x 0.9 mm

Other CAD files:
Librairy/3_pin_male_header/CONN_M20-99903XX_HRW.step
Librairy/ACM2012_900_2P_T002/AltiumDesigner/ACM2012_TDK.step
Librairy/C0805C104J8RACTU/CAPC220145_88N_KEM.step
Librairy/C0805C104K3RACTU/AltiumDesigner/CAPC220145_88N_KEM.step
Librairy/C0805C104K4RACAUTO/CAPC220145_88N_KEM.step
Librairy/C0805C150K4GACTU/AltiumDesigner/CAPC220145_88N_KEM.step
Librairy/C0805C150K5RACAUTO/AltiumDesigner/CAPC220145_88N_KEM.step
Librairy/C0805C221M5RACTU/CAPC220145_88N_KEM.step
Librairy/C0805C222K3GECTU/AltiumDesigner/CAPC480350_110N_KEM.step
Librairy/C0805C472K4RACTU/AltiumDesigner/CAPC220145_88N_KEM.step
Librairy/CGA4J3X5R1H475K125AB/AltiumDesigner/CAP_2012_TDK.step
Librairy/Capacitor_0805/AltiumDesigner/CAP_CC0805_YAG.step
Librairy/Capacitor_0805/CAP_CC0805_YAG.step
Librairy/ECS_250_8_37B2_RWY_TR/ECS-250-8-37B2-RWY-TR.STEP
Librairy/ERA_3AEB472V/RC0603N_PAN.step
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

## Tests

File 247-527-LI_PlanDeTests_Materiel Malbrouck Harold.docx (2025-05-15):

Projet de fin de DEC H25

PLAN DE TESTS

CONCEPTION MATÉRIELLE

Nom du projet : DARKYDEN

Révision :A

PRÉNOM | Harold Jonathan
NOM | Malbrouck
DATE | 2025-05-12

Les essais À FAIRE doivent être en BLEU PÂLE : [À FAIRE] AAAA-MM-JJ

Les essais complétés et réussis doivent être inscrits en VERT : [PASS] AAAA-MM-JJ

Les essais complétés et non réussis doivent être inscrits en ROUGE : [FAIL] AAAA-MM-JJ

# 1 SECTION INSPECTION PRÉLIMINAIRE

## 1.1 Tests de continuité [À FAIRE] 2025-05-12

ÉLÉMENT À TESTER (DESCRIPTION) | CONDITIONS | CRITÈRES | MESURES | RÉSULTATS
Pas de court-circuit entre 12V et GND (TP_12V et TP_GND4) | Darkyden éteint | Mesure d’impédance > 50 Ω
Pas de court-circuit entre 5V et GND (TP_5V et TP_GND1) | Darkyden éteint | Mesure d’impédance > 50 Ω
Pas de court-circuit entre 3.3V et GND (TP_3V3 et TP_GND2) | Darkyden éteint | Mesure d’impédance > 50 Ω
Pas de court-circuit entre 1.8V et GND (TP_1V8 et TP_GND3) | Darkyden éteint | Mesure d’impédance > 50 Ω

# 2 SECTION MÉCANIQUE ET DIMENSIONS

## 2.1 Mesures et tolérances [À FAIRE] 2025-05-12

ÉLÉMENT À TESTER (DESCRIPTION) | CONDITIONS | CRITÈRES | MESURES | RÉSULTATS
Position des 4 connecteurs pour le CM3588 | (TOL : +/- 0.01mm) | Alignement parfait des connecteurs

## 2.2 Intégrité mécanique [À FAIRE] AAAA-MM-JJ

ÉLÉMENT À TESTER (DESCRIPTION) | CONDITIONS | CRITÈRES | MESURES | RÉSULTATS
Solidité, rigidité et fixation | -
Fixation des pièces lourdes | -
Pièces mobiles Choix de la visserie (type, longueur) | -
Vérification de la peinture (couleur, fini, texture, tenue, etc.)
Protection mécanique des composants fragiles | -
Espace libre autour des points de fixation | -
Espace libre autour des points de test | -
Esthétique | -
Le PCB s'insère parfaitement dans son boitier de plastique | -

# 3 SECTION ALIMENTATION

## 3.1 Essais No1 [À FAIRE] 2025-05-12

ÉLÉMENT À TESTER (DESCRIPTION) | CONDITIONS | CRITÈRES | MESURES | RÉSULTATS
Sortie du régulateur IC5 | Vin = +12V ±7% | Vout = +5V ±5
Sortie du régulateur IC6 | Vin = +12V ±7% | Vout = +3.3V ±5
Sortie du régulateur IC6 | Vin = +12V ±7% | Vout = +3.3V ±5
Sortie du régulateur IC7 | Vin = +12V ±7% | Vout = +1.8V ±5

# 4 SECTION LIEN COMMUNICATION

## 4.1 UART [À FAIRE] AAAA-MM-JJ

ÉLÉMENT À TESTER (DESCRIPTION) | CONDITIONS | CRITÈRES | MESURES | RÉSULTATS
S/O
S/O
S/O

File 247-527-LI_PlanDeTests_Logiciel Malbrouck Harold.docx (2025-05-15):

Projet de fin de DEC H25

PLAN DE TESTS

CONCEPTION LOGICIELLE

Nom du projet : DARKYDEN

Révision : A

PRÉNOM | Harold Jonathan
NOM | Malbrouck
DATE | 2025-05-12

Les essais À FAIRE doivent être en BLEU PÂLE : [À FAIRE] AAAA-MM-JJ

Les essais complétés et réussis doivent être inscrits en VERT : [PASS] AAAA-MM-JJ

Les essais complétés et non réussis doivent être inscrits en ROUGE : [FAIL] AAAA-MM-JJ

# 1 REVISION DE LOGICIEL OU DES LOGICIELS UTILISÉS

## 1.1 Révision utilisée [À FAIRE] 2025-05-12

Jouter le nom et la version du logiciel utilisé.

Linux Debian ou Gentoo

# 2 SECTION DÉMARRAGE.

## 2.1 Essais # 1 [À FAIRE] AAAA-MM-JJ

ÉLÉMENT À TESTER (DESCRIPTION) | CONDITIONS | CRITÈRES | MESURES | RÉSULTATS
APPUYER SUR LE BOUTON de démarrage | | DEL D2 s’allume. Écran affiche le logo de linux puis le bureau

# 3 SECTION AFFICHAGE

## 3.1 Essais # 1 [À FAIRE] AAAA-MM-JJ

DÉCRIRE LE COMPORTAMENT DU LOGICIEL ET LES RÉSULTATS ATTENDUS.

ÉLÉMENT À TESTER (DESCRIPTION) | CONDITIONS | CRITÈRES | MESURES | RÉSULTATS
Appuyer sur la flèche xyz | | Écran affiche xxxx

## 1.1 Essais # 2 [À FAIRE] AAAA-MM-JJ

DÉCRIRE LE COMPORTAMENT DU LOGICIEL ET LES RÉSULTATS ATTENDUS.

ÉLÉMENT À TESTER (DESCRIPTION) | CONDITIONS | CRITÈRES | MESURES | RÉSULTATS

# 4 SECTION LIEN COMMUNICATION AVEC FIL

## 4.1 UART [À FAIRE] AAAA-MM-JJ

ÉLÉMENT À TESTER (DESCRIPTION) | CONDITIONS | CRITÈRES | MESURES | RÉSULTATS
Envoyer la commande xyz | | L’appareil affiche xyz . DEL Dx devient ON.

# 5 SECTION LIEN COMMUNICATION SANS FIL

## 5.1 Section Bluetooth et appairage des devices [À FAIRE] AAAA-MM-JJ

ÉLÉMENT À TESTER (DESCRIPTION) | CONDITIONS | CRITÈRES | MESURES | RÉSULTATS

## 1.1 Section wifi [À FAIRE] AAAA-MM-JJ

ÉLÉMENT À TESTER (DESCRIPTION) | CONDITIONS | CRITÈRES | MESURES | RÉSULTATS

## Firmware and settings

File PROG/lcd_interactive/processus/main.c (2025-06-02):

//************************************************************************************
// Nom du fichier : main.c
// Auteur : Harold Malbrouck
//
// Date de création : 30 Mai 2025
// Rev : 1.0
//       2.0 01 Juin 2025
//
// Description : Point d’entrée de l’application LCD interactive sur CM3588.
//               Initialise les pilotes LCD et clavier, puis lance la boucle principale
//               qui affiche un menu interactif selon les touches pressées.
//
//************************************************************************************
#include "../include/serviceMenu.h"
#include "../include/interfaceClavier.h"
#include "../include/interfaceLCD.h"
//#include "../include/serviceAnimation.h"
#include <stdio.h>
#include <stdlib.h>
#include <unistd.h>
#include <syslog.h>

int main() {
    openlog("lcd_demo", LOG_PID | LOG_CONS, LOG_USER);
    syslog(LOG_INFO, "Démarrage de l'application LCD interactive");

    // Initialisation de l'écran LCD
    if (interfaceLCD_init("/dev/i2c-8", 0x27) < 0) {
        syslog(LOG_ERR, "Erreur d'initialisation LCD");
	fprintf(stderr,"LCD INITT FAILED\\n");
        return EXIT_FAILURE;
    }
    
	// Initialisation du clavier I²C
    if (interfaceClavier_init("/dev/gpiochip3", 10, "/dev/i2c-8", 0x14) < 0) {
        syslog(LOG_ERR, "Erreur d'initialisation clavier");
	fprintf(stderr,"Clavier INIT FAILED\\n");
        return EXIT_FAILURE;
    }
    
	// Affichage du menu principal
    serviceMenu_afficher();

    // Boucle principale d'interaction
    while (1) {
        char touche = interfaceClavier_attendreTouche();
        if (touche) {
            syslog(LOG_INFO, "Touche reçue : %c", touche);
            serviceMenu_traiterTouche(touche);
        }
        sleep(1);
    }

    closelog();
    return EXIT_SUCCESS;
}

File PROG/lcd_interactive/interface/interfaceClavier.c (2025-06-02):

//************************************************************************************
// Nom du fichier : interfaceClavier.c 
// Auteur : Harold Malbrouck 
//
// Date de création : 30 Mai 2025
//
// Description : Module qui gère l'interruption GPIO et la lecture I2C du clavier 4x4.
//               Ce clavier est connecté via un microcontrôleur (PIC16F88) sur I²C,
//               avec une ligne GPIO en interruption (INT) lorsque l’utilisateur appuie.
//************************************************************************************

#include "../include/interfaceClavier.h"
#include "../include/piloteI2C.h"
#include <gpiod.h>
#include <unistd.h>
#include <syslog.h>
#include <fcntl.h>
#include <poll.h>
#include <stdio.h>

// --- Variables internes ---
static int clavier_fd = -1;                     // File descriptor I2C du clavier
static struct gpiod_line *ligne_int = NULL;     // Ligne GPIO utilisée pour l'interruption
static struct gpiod_chip *puce_gpio = NULL;     // Puce GPIO

int interfaceClavier_init(const char *chipname, int ligne_gpio, const char *i2c_device, int i2c_addr) {
//*******************************************************************************************
// Initialise le clavier :
// 1. Initialise la communication I2C avec l'adresse donnée.
// 2. Configure l’interruption GPIO via libgpiod avec résistance pull-up.
//
// @param chipname     Exemple : "/dev/gpiochip3"
// @param ligne_gpio   Numéro de ligne GPIO à utiliser pour l’INT (ex: 10 pour GPIO3_B2)
// @param i2c_device   Exemple : "/dev/i2c-8"
// @param i2c_addr     Adresse I2C du PIC (ex: 0x14)
// @return 0 si succès, -1 si échec
//********************************************************************************************
    
	// Ouverture du bus I2C
    clavier_fd = piloteI2C_initialise(i2c_device, i2c_addr);
    if (clavier_fd < 0) {
        syslog(LOG_ERR, "Erreur ouverture clavier I2C");
        return -1;
    }

    // Ouverture de la puce GPIO
    puce_gpio = gpiod_chip_open(chipname);
    if (!puce_gpio) {
        syslog(LOG_ERR, "Erreur ouverture chip GPIO");
        return -1;
    }

    // Récupération de la ligne GPIO à utiliser
    ligne_int = gpiod_chip_get_line(puce_gpio, ligne_gpio);
    if (!ligne_int) {
        syslog(LOG_ERR, "Erreur récupération ligne GPIO");
        return -1;
    }

    // Configuration de la ligne pour recevoir les interruptions (front descendant, pull-up)
    if (gpiod_line_request_falling_edge_events_flags(
            ligne_int, "clavier", GPIOD_LINE_REQUEST_FLAG_BIAS_PULL_UP) < 0) {
        syslog(LOG_ERR, "Erreur demande événement d'interruption");
        return -1;
    }

    return 0;
}

char interfaceClavier_attendreTouche() {
//*******************************************************************************************
// Attend une interruption, puis lit un code via I²C.
// Si la lecture est correcte, le code est traduit en caractère clavier.
// Le code 0x20 est ignoré (aucune touche valide).
//
// @return Caractère de la touche ('0'-'9', 'A'-'D', '*', '#') ou '?' si inconnu
//*******************************************************************************************
    struct gpiod_line_event event;

    // Attente d’un événement d’interruption
    int ret = gpiod_line_event_wait(ligne_int, NULL);
    if (ret <= 0) return 0;

    if (gpiod_line_event_read(ligne_int, &event) < 0) {
        syslog(LOG_ERR, "Erreur lecture événement INT");
        return 0;
    }

    // Lecture I2C du code de touche depuis le microcontrôleur
    unsigned char buffer = 0;
    if (read(clavier_fd, &buffer, 1) != 1) {
        syslog(LOG_ERR, "Erreur lecture I2C touche");
        return 0;
    }

    // Filtrage du code 0x20 (aucune touche active détectée)
    if (buffer == 0x20) {
        syslog(LOG_INFO, "Code 0x20 ignoré (aucune touche)");
        return 0;
    }

    // Décodage du code I²C en caractère humain lisible
    char touche = '?';
    switch (buffer) {
        case 0x00: touche = '1'; break;
        case 0x01: touche = '2'; break;
        case 0x02: touche = '3'; break;
        case 0x03: touche = 'A'; break;
        case 0x04: touche = '4'; break;
        case 0x05: touche = '5'; break;
        case 0x06: touche = '6'; break;
        case 0x07: touche = 'B'; break;
        case 0x08: touche = '7'; break;
        case 0x09: touche = '8'; break;
        case 0x0A: touche = '9'; break;
        case 0x0B: touche = 'C'; break;
        case 0x0C: touche = '*'; break;
        case 0x0D: touche = '0'; break;
        case 0x0E: touche = '#'; break;
        case 0x0F: touche = 'D'; break;
        default:
            syslog(LOG_WARNING, "Code touche inconnu: 0x%02X", buffer);
            touche = '?';
            break;
    }

    return touche;
}

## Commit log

2025-04-02 motherboard library
    [20455-040E-76.SchLib, IPEX_20455-040E-76.PcbLib, motherboard.SCHLIB]
2025-04-09 USB_C done
    [2012670005.SchLib, 2012670005.stp, ACM2012-900-2P-T002.PcbLib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]
2025-04-15 PowerSyst under construct
    [Bus_M.2_Socket_M.SchLib, CONNECTEUR_1.SchDoc, DARKYDEN.PrjPcb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]
2025-04-21 i dont know
    [HDMI.SchDoc, PD_BQ_Ref_Design.SCHLIB, PD_BQ_Ref_Design_PCB.PcbLib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]
2025-04-21 backup added
    [12V_FROM_BATTERY.SchDoc, BATTERY_GESTION.SchDoc, C0805C103K5RACTU.PcbLib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]
2025-04-21 backup PC added
    [12V_FROM_BATTERY.SchDoc, BATTERY_GESTION.SchDoc, CONNECTEUR_1.SchDoc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]
2025-04-25 ajout bakup 2025-04-024
    [0603_LED.PcbLib, 12V_FROM_BATTERY.SchDoc, 2N7002WT1G.PcbLib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]
2025-04-25 minor change
    [DARKYDEN.PrjPcb]
2025-05-10 routing done
    [0603_LED.PcbLib, 12V_FROM_BATTERY.SchDoc, 12V_PWR.SchDoc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]
2025-05-15 update BOM and sch
    [12V_PWR.SchDoc, 1V8_3V3_5V.SchDoc, BATTERY_GESTION.SchDoc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]
2025-06-02 final commit
    [0603_LED.PcbLib, 12V_PWR.SchDoc, 1V8_3V3_5V.SchDoc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]
